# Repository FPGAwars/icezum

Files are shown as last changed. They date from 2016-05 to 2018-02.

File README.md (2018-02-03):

# Icezum Alhambra
Arduino/zum compatible **Open FPGA** electronic board.  Synthesize hardware easily, using **only open source tools**

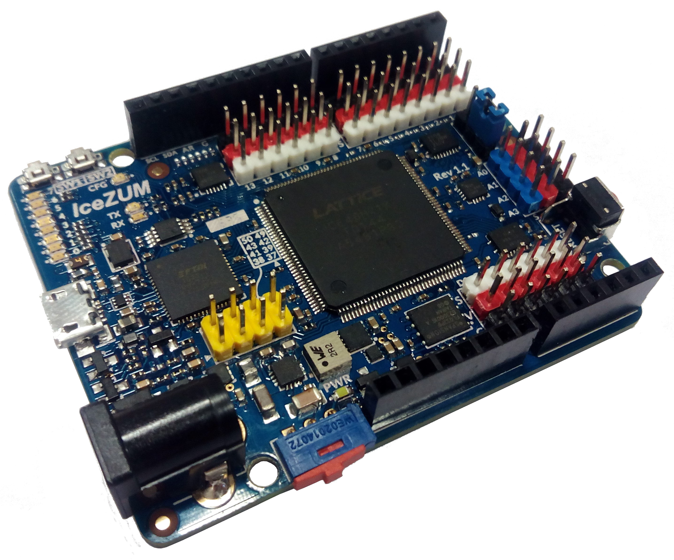
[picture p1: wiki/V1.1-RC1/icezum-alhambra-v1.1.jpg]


## Features

* FPGA development board ([iCE40HX1K-TQ144](https://github.com/Obijuan/open-fpga-verilog-tutorial/raw/master/tutorial/doc/iCE40LPHXFamilyDataSheet.pdf) from lattice)
* Open hardware
* Compatible with the [opensource icestorm toolchain](http://www.clifford.at/icestorm/)
* Arduino like board: similar pinout than Arduino one / [BQ zum](https://store.bq.com/es/placa-zum-core).
* You can Reuse most of available shields
* Control your robots / printbots from an FPGA
* 12 MHZ MEMS oscillator
* ON/OFF switch (turn off your mobile robot easily)
* Input power voltage: 6 - 17v
* Max input current: 3A (Perfect for powering your robots)
* 20 Input/output 5v pins
* 8 Input/Output 3.3V pins
* USB micro-B connector for programming the FPGA from the PC (same as zum board)
* [FTDI 2232H](www.ftdichip.com/Documents/DataSheets/ICs/DS_FT2232H.pdf) USB device allows FPGA programming and UART interface to a PC
* Reset pushbutton
* 8 general purpose leds (user leds)
* 2 general purpose pushbuttons
* 4 analogue inputs though I2C bus ([ADS7924](http://www.ti.com/lit/ds/symlink/ads7924.pdf) from TI)

## Documentation

[The project documentation is located in the wiki](https://github.com/FPGAwars/icezum/wiki)

## History

### Icezum Alhambra releases and EDA tools used over time

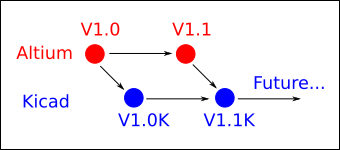
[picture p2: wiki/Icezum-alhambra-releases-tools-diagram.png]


### V1.0
* **2015-12-20**: The icezum board was conceived in the **BQlabs**, the robotics and innovation department at [BQ](https://www.bq.com/es/). The idea was to have a very easy to use FPGA board, fully openhardware, similar to Arduino/ZUM boards, so that anyone can connect sensors and create robots or small projects using an FPGA instead of a processor. We wanted to extend the educational approach of BQ to the digital circuits design. At that time, Juan Gonzalez (Obijuan) was the head of the department. Eladio Delgado, a very-skilled senior external engineer was assigned the task of designing the board. He was already involve in other projects with BQ

* **2016-02-18**: [The icezum board bqlabs repo](https://github.com/bqlabs/icezum) at github is created and all the V1.0 files released

*  **2016-02-29**: The board was renamed to **Icezum Alhambra** because Eladio lives in a small town in Granada. The name was suggested by **Sebastián Gallardo** in [this post in the FPGAwars community](https://groups.google.com/d/msg/fpga-wars-explorando-el-lado-libre/f1W0Vtt5NdE/LEDRSXudGwAJ) (In Spanish)

* **2016-03-05**: The first prototype is built and a bitstream is successfully upload into the board! [Images](https://github.com/FPGAwars/icezum/raw/master/doc/2016-03-04-Mounting-first-prototype/icezum-alhambra-mounting-15.jpg) 10 PCBs were manufactured in total. 5 Prototypes were mounted (by hand) by Eladio and his sister María. 5 more were mounted one mounth later

* **2016-04-14**: BQlabs was disolved and this proyect was stopped. Many thanks to BQ  for all its help during this period. Thanks for sponsoring the Icezum board

### V1.0K
* **2016-04-20**: The project is continued by the FPGAwars community, lead by Obijuan. The [FPGAwars github organization](https://github.com/FPGAwars)) is created and all the repositories related to openfpgas are moved there

* **2016-05-01**: A Small local crowdfunding is organized in the FPGAwars community ([Original message, in spanish](https://groups.google.com/d/msg/fpga-wars-explorando-el-lado-libre/oLFzYPqCOcQ/OsMxYKnuAQAJ)). Only 100 V1.1 boards will be manufactured if an amount of 6500€ is raised

* **2016/05/18**: After two weeks, we already have the commitment of the people for paying the money for building the boards ([Board funded!](https://groups.google.com/d/msg/fpga-wars-explorando-el-lado-libre/oLFzYPqCOcQ/luBcnXpBBwAJ))

* **2016/05/30**: The icezum Alhambra is being **migrated to Kicad** by Juan Gonzalez (Obijuan). Also the 3D models were designed with FreeCAD, so that the Icezum Alhambra is not only an openhardware board, but also a board **designed with opensource tools**. This way, anyone in the world can easily have access to all the designs, to study them, modify them and creating new boards from them. This version will be called V1.0K (K stands for kicad). It is not going to be manufactured, but rather a starting point for the future versions

* **2016/07/03**: All the money (6500€ in total) is received from the backers! Thanks a lot!!! ([Backers list](https://docs.google.com/spreadsheets/d/1yngU6kfMr5JWJYXrxBMJ7l1Cai2iuucMDoND4NpgU5Y))

* **2016/07/28**: V1.0K is released!

### V1.1

 * **2016/04/20**: In paralell with the V1.0K version, Eladio started to work on the V1.1, which is the one that will be manufactured for the backers. As there were still no Kicad version when Eladio started, It is being designed in Altium and will be migrated later to Kicad as the V1.1K version
 
 * **2016/09/22**: Three Icezum Alhambra V1.1-RC1 are hand mounted and tested. They work ok!. The PCBs were manufactured in pcbway. The design is validated

 * **2016/10/03**: [Icezum Alhambra v1.1-RC1 is released](https://github.com/FPGAwars/icezum/releases/tag/v1.1-RC1)
 
### V1.1K
 
 TODO

## Authors

* **V1.0**: [Eladio Delgado Mingorance](https://twitter.com/EladioDM). Sponsored by [BQ](https://www.bq.com/es/)
* **V1.0K**: Migrated to Kicad by Juan González (Obijuan). 3D models designed with FreeCAD. Everything is generated using only opensource tools (schematics, pcb, 3D models, pinout, BOM...). This version belongs to our T**echnological Heritage**
* **V1.1**: Eladio Delgado Mingorance, from Pinos del Valle, Granada, Spain

## Credits
* [BQ](https://www.bq.com/es/). Thanks for funding this project from 2015-12-20 to 2016-04-14. During this period, the icezum V1.0 was born and 10 prototypes were manufactured.
* María Delgado Mingorance, for helping in the manufacturing and design of the V1.0
* V1.0 was derived from the [Arduino Uno board](https://www.arduino.cc/en/Main/ArduinoBoardUno)
* V1.0 was derived from the [zum core board](https://github.com/bq/zum/tree/master/zum-core) by BQ
* V1.0 was derived from the [Icestick](http://www.latticesemi.com/icestick) by Lattice
* V1.0K was derived from Icezum Alhambra V1.0 by BQ
* V1.1 was derived from Icezum Alhambra V1.0 by BQ
* [Icestorm project](http://www.clifford.at/icestorm/), by Clifford Wolf and Mathias Lasser
* Icezum Pinout, by [Alberto Piganti](http://www.pighixxx.com/test/2016/05/icezum-pinout/)
* [Jairo Zerberos](https://github.com/zerberros). Migration of the FT2232H schematic symbol from altium to kicad. Thanks!
* [altium2kicad](https://github.com/thesourcerer8/altium2kicad]). Tool used for the migration from Altium to Kicad. Many thanks to the developers!
* [Kicadstepup](https://sourceforge.net/projects/kicadstepup/). Tool for exporting the board to FreeCAD
* [Alhambra festival picture](http://beentheredrawnthat.blogspot.com.es/2016/07/festivales-de-musica-y-danza-alhambra.html), by Cristina Urdiales. Thanks for this beautiful paiting!
* Juan González (Obijuan): V1.0 specifications. Migration to Kicad (V1.0K)

## Acknowledges
* Many thanks to [BQ](https://www.bq.com/es/), for funding the initial prototype V1.0, during the period 2015-12-20 to 2016-04-14. Thanks a lot for increasing our technological heritage by sponsoring openhardware boards.

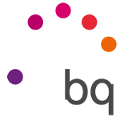
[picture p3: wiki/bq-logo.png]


## License

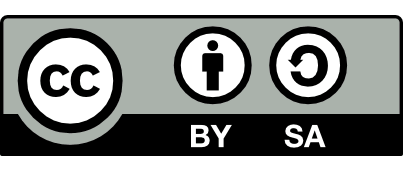
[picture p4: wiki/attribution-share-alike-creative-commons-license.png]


Licensed under [Creative Commons Attribution-ShareAlike 4.0 International License](http://creativecommons.org/licenses/by-sa/4.0/)

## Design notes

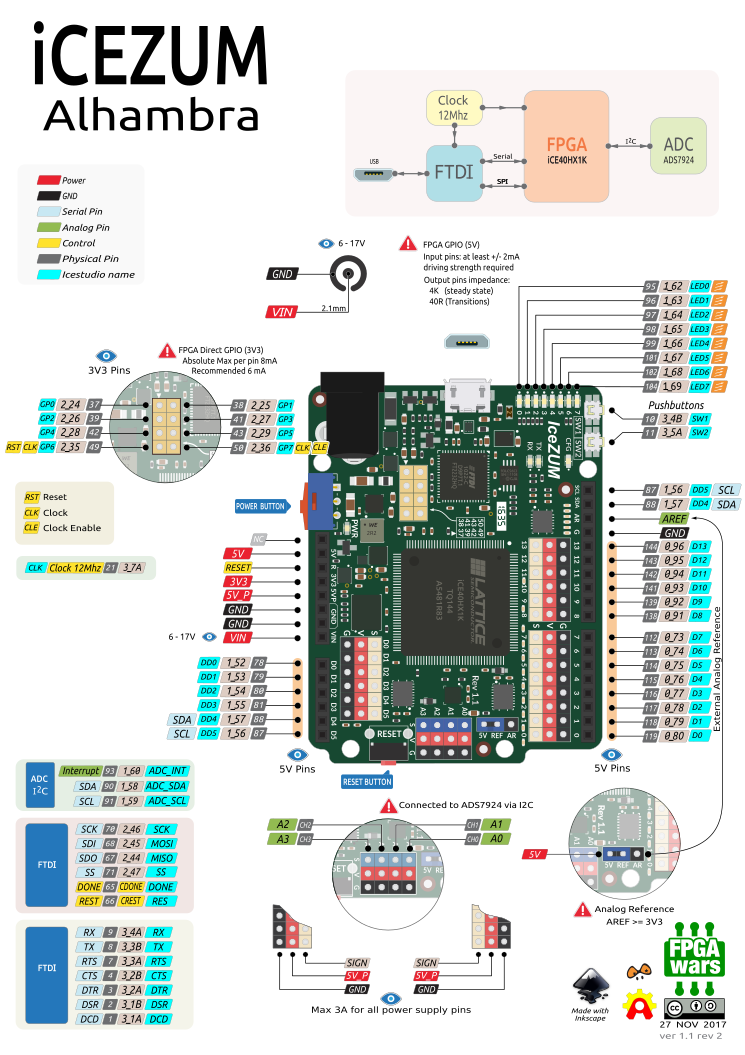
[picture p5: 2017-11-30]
doc/pinout/icezum-pinout.png

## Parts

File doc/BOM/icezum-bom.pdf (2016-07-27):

Icezum V1.0K BOM

ITEM | Reference | Description | Ordering Code | Manufacturer | Supplier | Footprint | Qty | OrderingCode 2 | Manufacturer 2 | Value
1 | C1,C2,C3,C4,C5,C6,C7,C8,C9,C10 C12,C13,C14,C15,C16,C18,C19 C20,C21,C23,C25,C26,C27,C28,C29 C30,C32,C33,C34,C35,C36,C37 C45,C46,C47,C48,C49,C50,C68 | SMD Capacitor | C0402C104K4RAC | Kemet | | C_0402 | 39 | | | 100nF ±10% 16V
2 | C11 | SMD Capacitor | EMK107BBJ106MA-T | Taiyo Yuden | | C_0603 | 1 | C1608X5R1C106M080AB | TDK | 10uF ±20% 16V
3 | C17,C24,C31,C41,C59,C64,C65 | SMD Capacitor | C1608X5R1C475K080AC | TDK | | C_0603 | 7 | | | 4.7uF ±10% 16V
4 | C22 | SMD Capacitor | C0603C103K3RAC | Kemet | | C_0603 | 1 | | | 10nF ±10% 25V
5 | C38,C39,C40,C42,C43,C44,C51, C52,C53,C54,C55,C56,C57,C58 | SMD Capacitor | C0402C101K4RAC | Kemet | | C_0402 | 14 | | | 100pF ±10% 16V
6 | C60,C62,C66,C70 | SMD Capacitor | C0603C104K3RAC | Kemet | | C_0603 | 4 | | | 100nF ±10% 25V
7 | C67 | SMD Capacitor | TMK316B7106KL-TD | kemet | | C_1206 | 1 | | | 10uF ±10% 25V
8 | C69 | SMD Capacitor | LMK316ABJ226ML-T | Taiyo Yuden | | C_1206 | 1 | | | 22uF ±20% 10V
9 | C71 | SMD Capacitor | GRM1885C1E621JA01D | Murata | | C_0603 | 1 | | | 620pF ±5% 25V
10 | D1 | Schottky Diode | MMDL101T1G | On Semiconductor | | SOD-323 | 1 | | | 100mA 7V
11 | D2,D3,D4,D5,D6,D7,D8,D9 | LED | LY Q971-H1L2-36 | OSRAM Opto | | LED_0603 | 8 | HSMY-C190 | Avago Technologies | Yellow
12 | D10 | Protection, Bidirectional Transient suppression Diode | SMAJ17CA | Bourns | | DO-214AC | 1 | SMAJ17CA | Littelfuse
13 | D11 | Dual Schottky Diode Common Cathode | BAT54C-G3-08 | Vishay | | SOT-23 | 1 | BAT54C | Fairchild | 200mA 30V
14 | D12 | LED | LW Q38G-Q2R2-3K5L-1 | OSRAM Opto | | LED_0603 | 1 | | | White
15 | D13 | Zener Diode | BZX384C5V1-E3 | Vishay | | SOD-323 | 1 | | | 5V1
16 | F1 | PTC Resettable Fuse | MF-MSMF050-2 | Bourns | Abacus | F_1812 | 1
17 | F2 | Protection, USB ESD | 82400152 | Würth | Würth | SOT-563 | 1 | CDSOT563-0502 | Bourns
18 | J1 | Connector, USB Micro B | 10118192-0001LF | FCI | Abacus | USB_Micro-B | 1 | ZX62-B-5PA-11 | Hirose Connector
19 | J2,J13 | 1x6 pin Header 2.54mm | TSW-106-07-T-S-RED | Samtec | Samtec | 1x6-pin-header-2.54mm | 2 | | | Red
20 | J3,J14 | 1x6 pin Header 2.54mm | TSW-106-07-T | Samtec | Samtec | 1x6-pin-header-2.54mm | 2 | 613 006 111 21 | Würth Elektronik | Black
21 | J6,J12 | 1x6 pin Header 2.54mm | TSW-106-07-T-NATURAL | Samtec | Samtec | 1x6-pin-header-2.54mm | 2 | | | white
22 | J4 | Connector, 10 pin Socket Header | SSW-110-01-T-S | Samtec | Samtec | 1x10_socket-header-2.54mm | 1 | 613 010 118 21 | Würth Elektronik
23 | J5,J10 | 8 pin Socket Header 2.54mm | SSW-108-01-T-S | Samtec | Samtec | 1x8_Socket_header_2.54mm | 2 | 613 008 118 21 | Würth Elektronik
24 | J7 | 1x8 pin Header 2.54mm | TSW-108-07-T-S-RED | Samtec | Samtec | 1x8_pin_header_2.54mm | 1 | | | Red
25 | J8 | 1x8 pin Header 2.54mm | TSW-108-07-T-S | Samtec | Samtec | 1x8_pin_header_2.54mm | 1 | 613 008 111 21 | Würth Elektronik | Black
26 | J9 | 1x8 pin Header 2.54mm | TSW-108-07-T-S-NATURAL | Samtec | Samtec | 1x8_pin_header_2.54mm | 1 | | | White
27 | J11 | 6 pin Socket Header 2.54mm | SSW-106-01-T-S | Samtec | Samtec | 1x6-Socket-header-2.54mm | 1 | 613 006 118 21 | Würth Elektronik
28 | J15 | Connector, 1x4 pin Header 2.54mm | TSW-104-07-T-S-RED | Samtec | Samtec | 1x04-pin-header-2.54mm | 1 | | | Red
29 | J16 | Connector, 1x4 pin Header 2.54mm | TSW-104-07-T-S | Samtec | Samtec | 1x04-pin-header-2.54mm | 1 | 613 004 111 21 | Würth Elektronik | Black
30 | J17 | Connector, 1x4 pin Header 2.54mm | TSW-104-07-T-S-BLUE | Samtec | Samtec | 1x04-pin-header-2.54mm | 1 | 613 004 111 21 | Würth Elektronik | Cyan
31 | J18 | Connector, Power, DC Power Jack | KLDHCX0202A | Kycon | Avnet | JACK_2.1 | 1 | RAPC722X | Switchcraft
32 | J19 | Connector, 8 pin Dual Header 2.54mm | TSW-104-07-T-D | Samtec | Samtec | 2x04-pin-header-2.54mm | 1 | 613 008 211 21 | Würth Elektronik
33 | JP1 | Connector, Jumper, 3 pin Male Header 2.54mm | 613 003 111 21 | Würth | Würth | 1x03-pin-header-2.54mm | 1
34 | JPM1 | 1x2 Jumper 2.54mm | 609 002 136 21 | Würth | Würth | | 1
35 | L1 | Inductor SMD | LQM21FN100M70L | Murata | | L_0805 | 1 | | | 10uH 0,1A
36 | L2,L4 | Ferrite Bead | BLM18SG121TN1D | Murata | | L_0603 | 2 | | | 120R 0,025R 3000mA
37 | L3 | Ferrite Bead | MPZ1608S221A | TDK | | L_0603 | 1 | | | 220R 0,05R 2200mA
38 | L5 | Inductor SMD | 74438356022 | Würth | Würth | L_4040 | 1 | XAL4020-222MEB | Coilcraft | 2,2uH 4,7A
39 | Q1,Q2,Q4 | P-Channel MOSFET, 6 pin | DMP3017SFK-7 | Diodes Inc. | Silica | DFN-2523-6 | 3
40 | Q3 | PFET | DMP2035U-7 | Diodes Inc. | Silica | SOT-23 | 1
41 | Q5 | PNP | PMBT3906,215 | NXP | | SOT-23 | 1
42 | R1,R3,R4,R5,R6,R7,R8, R12,R13,R14 R20,R21,R28,R37,R38 | Resistor, SMD | CRCW040210K0JN | Vishay | | R_0402 | 15 | | | 10k±5% 0.063w
43 | R2 | Resistor, SMD | CRCW0402470RJN | Vishay | | R_0402 | 1 | | | 470R ±5% 0.063W
44 | R9 | Resistor, SMD | CRCW0402100RJN | Vishay | | R_0402 | 1 | | | 100R ±5% 0.063W
45 | R10,R25,R39 | Resistor, SMD | CRCW04021K00JN | Vishay | | R_0402 | 3 | | | 1k ±5% 0.063W
46 | R11 | Resistor, SMD | CRCW040212K0FK | Vishay | | R_0402 | 1 | | | 12k ±1% 0.063W
47 | R15 | Resistor, SMD | CRCW04022K20JN | Vishay | | R_0402 | 1 | | | 2k2 ±5% 0.063W
48 | R16,R32,R33,R35 | Resistor, SMD | ERJ-2GE0R00X | Panasonic | | R_0402 | 4 | CRCW04020000Z0 | Vishay | 0R ±5% 0.063W
49 | R17,R18 | Array of 4xResistors, SMD | CAY16-271J4LF | Bourns | | R_Array_Convex_4x0603 | 2 | | | 270R ±0,5% 0,0625W
50 | R19 | Resistor, SMD | CRCW040210R0JN | Vishay | | R_0402 | 1 | | | 10R ±5% 0.063W
51 | R22,R23 | Resistor, SMD | CRCW04024K70JN | Vishay | | R_0402 | 2 | | | 4k7 ±5% 0.063W
52 | R24,R27 | Resistor, SMD | CRCW040247K0JN | Vishay | | R_0402 | 2 | | | 47k ±5% 0.063W
53 | R26,R29,R30,R31 | Resistor, SMD | CRCW0402100KJN | Vishay | | R_0402 | 4 | | | 100k ±5% 0.063W
54 | R34 | Resistor, SMD | CRCW04025K60JN | Vishay | | R_0402 | 1 | | | 5k6 ±5% 0.063W
55 | R36 | Resistor, SMD | CRCW0402220KJN | Vishay | | R_0402 | 1 | | | 220k ±5% 0.063W
56 | SW1,SW2 | Micro miniature pushbutton Surface Switch | 434 121 025 816 | Würth | Würth | SW_SMD_60X3.8 | 2 | KSR231GLFS | Cannon, ITT ind.
57 | SW3 | SPDT Switch, Right Angle | 450 302 014 072 | Würth | Würth | slide-sw-spdt-right-angle | 1 | MMP1010D-RA | Knitter-Switch
58 | SW4 | Micro miniature pushbutton Surface Switch | PTS645VL39-2 LFS | C&K Components | Abacus | SW_vert_tht_7.5x6x6.5 | 1
59 | U1 | iCE40 HX1K Series FPGA Family, 1280 Logic Cells, 1.2 V Core, 64 K Embedded RAM Bits, 144-pin TQFP, Pb-Free, Tray | iCE40HX1K-TQ144 | Lattice | | TQFP-144_IPC-MD | 1
60 | U2 | NOR Flash Memory, serial | N25Q032A13EF640E | Micron | Silica | DFN-8-6x5mm | 1 | S25FL032P0XNFI011 | Spansion | 32Mb
61 | U3 | Dual High Speed USB to Multipurpose UART/FIFO IC | FT2232HQ-REEL | FTDI | Silica | FTDI-QFN-64 | 1
62 | U4 | Oscillator, Low-Power CMOS, 4 pin, 1.8-3.3V | DSC1001CL2-012.0000 | Microchip | | Xtal-3_2x2_5 | 1 | | | 12MHz
63 | U5 | EEPROM, 2K Microwire Compatible Serial, 8 or 16 bit word size, 2.5-5.5 Vcc range | 93LC56CT-I/MS | Microchip | Silica | MSOP-8_3x3mm_Pitch0.65mm | 1 | | | 2Kb
64 | U6 | Voltage Translator, Hex | TXB0106RGYR | Texas Instruments | Silica | VQFN16 | 1
56 | U7 | ADC Converter, 12-Bit, 4-Ch, I2C | ADS7924IRTER | Texas Instruments | Silica | QFN16 | 1
66 | U8 | Voltage Level Translator, 8-Bit Bidir., TP | TXS0108ERGYR | Texas Instruments | Silica | VQFN20 | 1
67 | U9 | Voltage Level Translator, 8-Bit Bidir., TP | TXB0108RGYR | Texas Instruments | Silica | VQFN20 | 1
68 | U10 | LDO Regulator, 8 pin, adjustable And fixed mode with enable | AP7361-33FGE-7 | Diodes Inc. | Silica | DFN-3030-8 | 1
69 | U11 | LDO Regulator, Dual, 6 pin | TLV7111233DSER | Texas Instruments | Silica | WSON-6 | 1
70 | U12 | 3A High Efficient Synchronous Step Down Converter with DCS™ Control | TPS62133RGTR | Texas Instruments | Silica | QFN16 | 1

Made with LibreOffice

Icezum Alhambra V1.0K (Kicad-edition) BILL OF MATERIALS

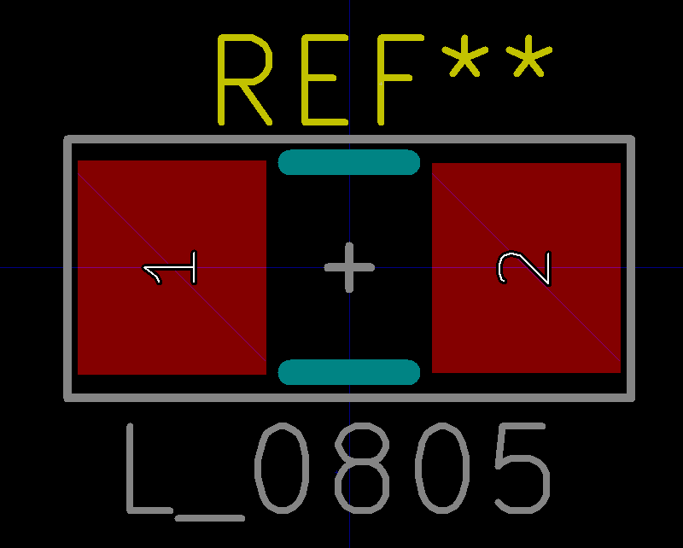
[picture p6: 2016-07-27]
wiki/V1.0K/3D-components/L_0805-footprint.png

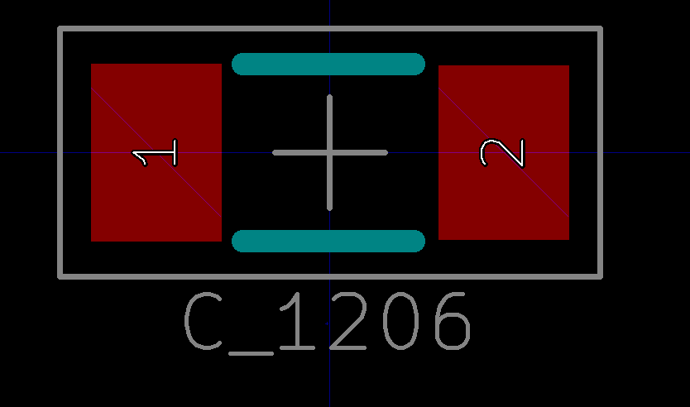
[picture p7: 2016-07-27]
wiki/V1.0K/3D-components/C_1206-footprint.png

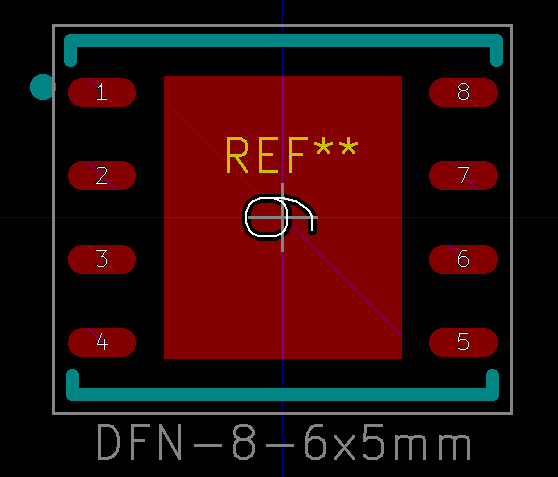
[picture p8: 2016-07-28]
wiki/V1.0K/3D-components/DFN-8-6X5mm-footprint.png

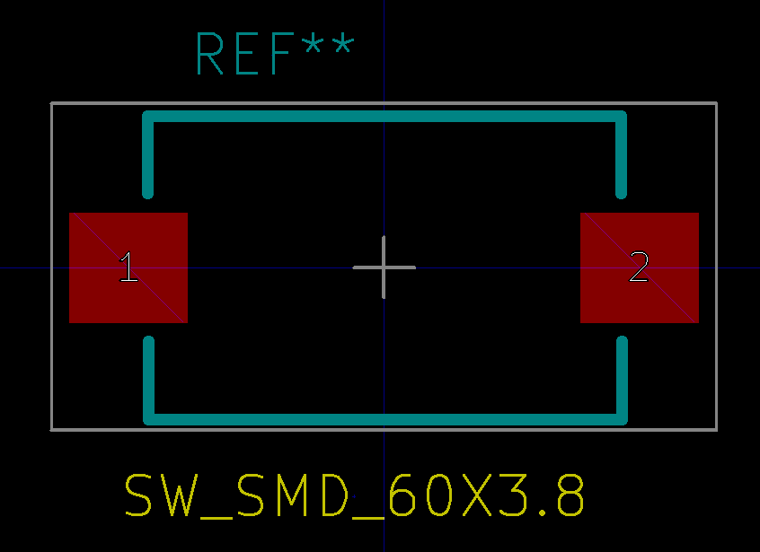
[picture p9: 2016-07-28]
wiki/V1.0K/3D-components/SW_smd_60x3.8-footprint.png

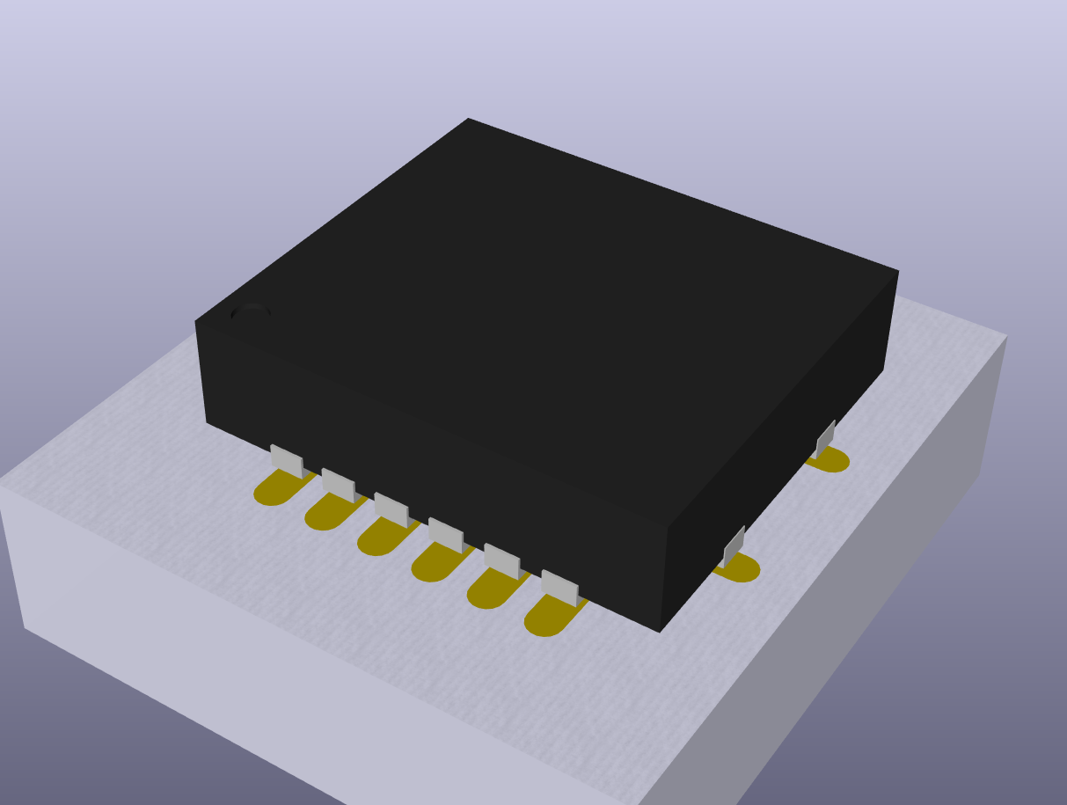
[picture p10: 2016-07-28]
wiki/V1.0K/3D-components/VQFN16-3D.png

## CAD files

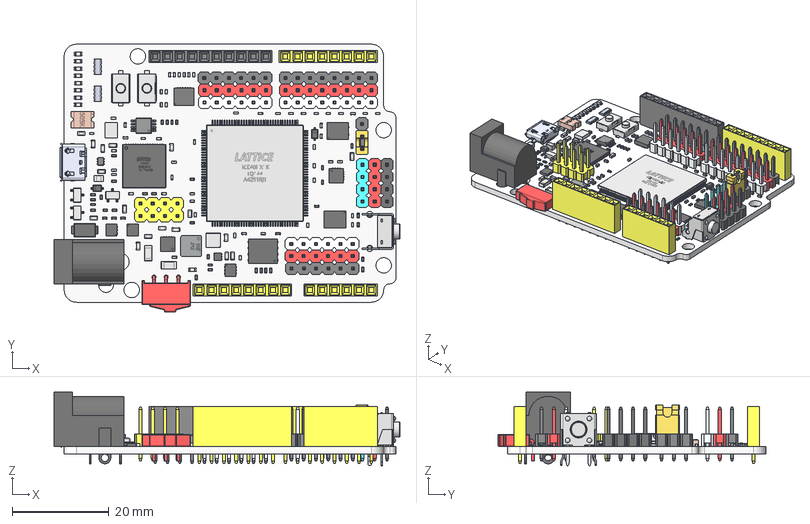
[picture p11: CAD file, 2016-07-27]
3D/icezum.FCStd
71.5 x 55.3 x 15.2 mm
Pcb
LED_0603_
LED_0603_001
LED_0603_002
LED_0603_003
LED_0603_004
LED_0603_005
LED_0603_006
LED_0603_007
sw_smd_6.0x3.8_
sw_smd_6.0x3.8_001
LED_0603_008
R_Array_4x0603_
R_Array_4x0603_001
PVQFN20_
PVQFN20_001
1x10-socket-header_
1x6-pin-header_
1x6-pin-header_001
1x6-male-pin-header-gray_
1x6-male-pin-header-gray_001
1x6-male-pin-header-red_
1x6-male-pin-header-red_001
1x8-socket-header_
1x8-male-pin-header_
1x8-male-pin-header-red_
1x8-male-pin-header-gray_
1x8-socket-header_001
1x6-socket-header_
1x4-male-pin-header_
1x4-male-pin-header-red004_
1x4-male-pin-header-cyan_
2x4-pin-header-yello_
USB-micro-B_
jack_DC_2.1mm_PCB_
slide-sw-right-angle_
F1812-505k_
xtal-3_2x2_5_
MSOP-8_
SOT-563_
SOT23-3_
SOT23-3_001
SOT23-3_002
SOD-323_
DO-214AC_
DFN-2523-6_
DFN-2523-6_001
FTDI-QFN-64_
QFN16_
QFN16_001
L_4040_
PVQFN16_
DFN-2523-6_002
TQFP-144_
DFN-3030-8_
WSON-6_
SOD-323_001
DFN-8-6x5mm_
pushbutton-right-angle_
L_0603_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

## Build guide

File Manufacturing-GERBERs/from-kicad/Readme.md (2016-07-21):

* **icezum-Edge.cuts.gbr**: Mechanical layer 1 (*icezum-GM1*)
* **icezum-F.Cu.gbr**: Copper Top layer (*icezum-GTL*)
* **icezum-B.Cu.gbr**: Copper Bottom layer (*icezum-GBL*)
* **icezum-In1.Cu.gbr**: Copper Inner layer 1 (*icezum-G1*)
* **icezum-In2.Cu.gbr**: Copper Inner layer 2 (*icezum-G2*)
* **icezum-F.SilkS.gbr**: Top SilkScreen Layer (*icezum-GTO*)
* **icezum-B.SilkS.gbr**: Bottom SilkScreen Layer (*icezum-GBO*)
* **icezum-F.Mask.gbr**: Top Solder Mask Layer (*icezum-GTS*)
* **icezum-B.Mask.gbr**: Bottom Solder Mask Layer (*icezum-GBS*)
* **icezum-F.Paste.gbr**: Top Paste layer (*icezum-GTP*)
* **icezum.drl**: Drills

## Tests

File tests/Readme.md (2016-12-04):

# Tests for the Icezum Alhambra v1.1  

Tools:  Apio 0.1.6.2  / Icestudio 0.2.1

* **Test 01**: Turning all leds on
* **Test 02**: Testing the pushbuttons. SW1 and SW2 are connected to led0 and led1 respectively
* **Test 03**: Testing the RTS and DTR signals coming from the PC. They are shown in the leds led0 and led7 respectively
* **Test 04**: Testing the serial communication at 115200 bauds. All the received characters are echoed back to the PC, and shown in the leds
* **Test 05**: Testing the external IR sensors on D13 and D12 inputs
* **Test 06**: Testing a servo connected to D13. The position is changed when the SW1 button is pressed

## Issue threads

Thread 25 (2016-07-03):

KiCad example loading

gh-jmg, 2016-07-03:
Hi,
Nice project. Checking the nice KiCad ported files you have I see some small issues

a) SCH files open, but minus some symbols.
    I need to go Preferences.Component Libraries, and add your local library to the list.
   Then, all symbols render OK

b) icezum.KiCad_pcb seems load parts and outline correctly, but looks to be 100% unrouted ? (no traces?)
Or, is it intentional this is unrouted ?

Obijuan, 2016-07-03:
Hi!

Thanks for you feedback

a) Checkout the develop branch and test it again: https://github.com/FPGAwars/icezum/tree/develop

The library should be automatically loaded. If not, please, tell me in this issue

b) The board is currently being routed in the develop branch. All the placement is finished, all the 3D component have modeled (in freecad) and the routing is 20% (only the first layer). I hope that the migration to kicad will be finished in around two weeks

Any feedback is welcome :-)

gh-jmg, 2016-07-03:
Hi Juan,

a) Checkout the develop branch and test it again:
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
I'll check this tomorrow.

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
ok, I was not sure if that unrouted was accidental.Look forward to seeing
the finished design.
If you do this in Altium, you could consider release of both P-CAD and
KiCad formats, as the kiCad PCAD importer is being improved all the time.
That also allows Eagle users to import the design too.

Did you consider doing anything with the Lattice 48 pin QFN iCE5x series ?
They still lack an eval board for those....

Obijuan, 2016-07-03:
> If you do this in Altium, you could consider release of both P-CAD and KiCad formats, as the kiCad PCAD importer is being improved all the time. That also allows Eagle users to import the design too.

Thanks for the tip!

> Did you consider doing anything with the Lattice 48 pin QFN iCE5x series ? They still lack an eval board for those....

I am not sure if that series are supported by the opensource icestorm toolschain. If not, they will be in the future, I am sure

gh-jmg, 2016-07-05:
Hi Juan,

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
I'm curious, if you have this routed in Altium, why do you need to re-route
it in KiCad ?
Did the porting/translation pathways have some issues ?

-jg

Obijuan, 2016-07-05:
I am just routing it myself for learning Kicad. Also for learning all the icezum details. The board was routed by Eladio, a college of mine, in Altium. I want to re-do it again in Kicad, for having in mind all the details.

gh-jmg, 2016-07-05:
HI Juan,

I am just routing it myself for learning Kicad.
>
Ah, that makes sense.

> Also for learning all the icezum details.
>
The board was routed by Eladio, a college of mine, in Altium.
>
I want to re-do it again in Kicad, for having in mind all the details.
>
You should be able to import from Altium, but I guess it depends on how
many changes are also merged in.
I've found KiCad seems to tolerate small end alignment deviations, (ie
slightly off exact pad centre)

I'm also new to KiCad, but it is growing on me,
The Shove router is very nice, and has better cleaning algorithms than
Mentors.
The mouse wheel navigation with rate-based zoom is also novel, and the more
I use that, the more adept I get and the more I like it. One hand for
navigate and one hand for commands, is nice.

gh-jmg, 2016-07-22:
Hi Juan,

I see a finished? design recently posted - looks nice :)

Some comments/observations

C31 is labeled 4.7nF, but maybe meant 4.7uF ?

When I use MicroUSB, I choose ones with through-holes (eg 4x)  on the outer
framework.
Usually those are short, (< 1.6mm), but give both location and more
strength and less likely to 'rip-off' from accidents.

regards
Jim G.

Obijuan, 2016-07-24:
>  see a finished? design recently posted - looks nice :)

Thanks! It is almost finished

> Some comments/observations C31 is labeled 4.7nF, but maybe meant 4.7uF ?

Yeah! It is a bug. I've already fix it in [this commit](https://github.com/FPGAwars/icezum/commit/6cd7838ead1d836aee266f3c594ddf4b5326ba79).  Thanks a lot for reporting:-)

> When I use MicroUSB, I choose ones with through-holes (eg 4x) on the outer framework. Usually those are short, (< 1.6mm), but give both location and more strength and less likely to 'rip-off' from accidents

Thanks for the advice. It makes more sense to use your MicroUSB.  We will use them in future versions

I will close this issue. If you have further comments or bugs, please do not hesitate on filling a issue

Thanks for you help  ;-)

gh-jmg, 2016-08-16:
Hi Juan,

Using this design as a nice test for kiCad scripts, I notice a couple of
things :

a) There are a few thermal vias, that have imported as parts from Altium

This gives a skew to the BOM and netlist
BOM has ~ 26 extra parts like this...
VIA**   pad-via
VIA**   pad-via
Netlist has 26 extra nodes
VIA**.~

BOM and Netlist will be cleaner, & need less manual cleanup, if those
Thermal Vias can be swallowed into the footprints ?

b) Some entities are modules with zero pads, so I added a test to skip
these.
(These can also confuse the BOM )
These may be just dummy place keepers ?

*REMARK* Skipped doc1 (has 0 Pads)
*REMARK* Skipped DOC1 (has 0 Pads)
*REMARK* Skipped doc7 (has 0 Pads)
*REMARK* Skipped doc2 (has 0 Pads)
*REMARK* Skipped doc3 (has 0 Pads)
*REMARK* Skipped doc10 (has 0 Pads)
*REMARK* Skipped DOC3 (has 0 Pads)
*REMARK* Skipped doc4 (has 0 Pads)
*REMARK* Skipped doc5 (has 0 Pads)
*REMARK* Skipped doc6 (has 0 Pads)
*REMARK* Skipped doc8 (has 0 Pads)
*REMARK* Skipped doc9 (has 0 Pads)
*REMARK* Skipped JPM1 (has 0 Pads)
*REMARK* Skipped DOC4 (has 0 Pads)
*REMARK* Skipped DOC5 (has 0 Pads)
*REMARK* Skipped G*** (has 0 Pads)
*REMARK* Skipped REF*** (has 0 Pads)
*REMARK* Skipped DRILL2 (has 0 Pads)
*REMARK* Skipped DRILL4 (has 0 Pads)
*REMARK* Skipped DRILL3 (has 0 Pads)
*REMARK* Skipped DRILL1 (has 0 Pads)

regards
Jim G

Obijuan, 2016-08-16:
Hi @gh-jmg !

I've created two new issues to discuss there: #28 and #29

Thanks a lot!

gh-jmg, 2016-08-18:
Hi Juan,

FYI, I just came across this
http://www.zofzpcb.com/

A 3D Gerber viewer, quite impressive.
I plotted using Altium GBR names, which it seems to better sense of, & I
drop a .D356 file into the GBR directory.

It can also load IPC356, and check a design.

So,  I feed latest Icezum into this.... just to see what happens...

See attached image - it has mostly inferred correct 3D info :)

The Via** parts have confused it a little, as it thinks they are all *one*
part, so it makes a  single, large rectangle covering all Via**, and it
also thinks they are pins, so renders as that, with 'bonus spines'.

Moving those thermal vias into footprints, (or even just as manual Vias) as
suggested before, should clean that up.

It renders non-trace holes differently from trace-holes for some strange
reason, I think a ZofzPCB bug ?

It renders U6 with a strange angle spin, not sure why ?

Hmm, looking closely, U6 is unusual, and it has guessed a ~SO16N (almost,
pin pitch is *not* same on each side ?), and maybe the pin-centroid is
skewed (tho centroid seems square to me ?)
That may be a ZofzPCB quirk, but is is doing a quite good job of inferring
3D onto the Gerber + IPC info

Attached is the Screen grab, and the IPC error report.

 I see some Gerbers from your github have teardrops - were those Kicad
plotted ?

There is this
https://forum.kicad.info/t/yet-another-python-teardrop-script-adds-and-deletes-teardrops-to-a-pcb-v0-3-0/3388
I suggested he add Curved Teardrops, and they are now in :) - I've not
tested this yet.

ICP356 Netlis v.s. PCB copper test
965 total testpoints processed

27 of No-copper testpoint errors
No copper for Testpoint +5V_P layer both at (41.7,  43.8)mm
No copper for Testpoint +5V_P layer both at (39.1,  43.8)mm
No copper for Testpoint +5V_P layer both at (36.6,  43.8)mm
No copper for Testpoint +5V_P layer both at (34.0,  43.8)mm
No copper for Testpoint +5V_P layer both at (31.5,  43.8)mm
No copper for Testpoint +5V_P layer both at (29.0,  43.8)mm
No copper for Testpoint +5V_P layer both at (47.0,  9.5)mm
No copper for Testpoint +5V_P layer both at (49.5,  9.5)mm
No copper for Testpoint +5V_P layer both at (52.1,  9.5)mm
No copper for Testpoint +5V_P layer both at (54.6,  9.5)mm
No copper for Testpoint +5V_P layer both at (57.2,  9.5)mm
No copper for Testpoint +5V_P layer both at (59.7,  9.5)mm
No copper for Testpoint +5V_P layer both at (63.5,  43.8)mm
No copper for Testpoint +5V_P layer both at (61.0,  43.8)mm
No copper for Testpoint +5V_P layer both at (58.4,  43.8)mm
No copper for Testpoint +5V_P layer both at (55.9,  43.8)mm
No copper for Testpoint +5V_P layer both at (53.3,  43.8)mm
No copper for Testpoint +5V_P layer both at (50.8,  43.8)mm
No copper for Testpoint +5V_P layer both at (48.3,  43.8)mm
No copper for Testpoint +5V_P layer both at (45.7,  43.8)mm
No copper for Testpoint NET-(J5-PAD1) layer both at (27.9,  2.5)mm
No copper for Testpoint +5V_P layer both at (64.2,  28.4)mm
No copper for Testpoint +5V_P layer both at (64.2,  25.9)mm
No copper for Testpoint +5V_P layer both at (64.2,  23.3)mm
No copper for Testpoint +5V_P layer both at (64.2,  20.8)mm
No copper for Testpoint NET-(J18-PAD2) layer both at (8.7,  3.6)mm
No copper for Testpoint NET-(SW3-PAD1) layer both at (18.6,  5.2)mm

0 of Short-Circuit errors
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

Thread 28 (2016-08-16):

Include the thermal vias in the footprints

Obijuan, 2016-08-16:
Reported by @gh-jmg:

Hi Juan, Using this design as a nice test for kiCad scripts, I notice a couple of things :

a) There are a few thermal vias, that have imported as parts from Altium
This gives a skew to the BOM and netlist
 BOM has ~ 26 extra parts like this...
VIA** pad-via
 VIA** pad-via
 Netlist has 26 extra nodes
 VIA**.~

BOM and Netlist will be cleaner, & need less manual cleanup, if those Thermal Vias can be swallowed into the footprints ?

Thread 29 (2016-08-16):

Modules with 0 pads confuse BOM

Obijuan, 2016-08-16:
Reported by @gh-jmg

Hi Juan,

Using this design as a nice test for kiCad scripts, I notice a couple of things :

b) Some entities are modules with zero pads, so I added a test to skip these. (These can also confuse the BOM ) These may be just dummy place keepers ?

 *REMARK* Skipped doc1 (has 0 Pads)
 *REMARK* Skipped DOC1 (has 0 Pads)
*REMARK* Skipped doc7 (has 0 Pads)
*REMARK* Skipped doc2 (has 0 Pads)
*REMARK* Skipped doc3 (has 0 Pads)
*REMARK* Skipped doc10 (has 0 Pads)
*REMARK* Skipped DOC3 (has 0 Pads)
*REMARK* Skipped doc4 (has 0 Pads)
*REMARK* Skipped doc5 (has 0 Pads)
*REMARK* Skipped doc6 (has 0 Pads)
*REMARK* Skipped doc8 (has 0 Pads)
*REMARK* Skipped doc9 (has 0 Pads)
*REMARK* Skipped JPM1 (has 0 Pads)
*REMARK* Skipped DOC4 (has 0 Pads)
*REMARK* Skipped DOC5 (has 0 Pads)
*REMARK* Skipped G*** (has 0 Pads)
*REMARK* Skipped REF*** (has 0 Pads)
*REMARK* Skipped DRILL2 (has 0 Pads)
*REMARK* Skipped DRILL4 (has 0 Pads)
*REMARK* Skipped DRILL3 (has 0 Pads)
*REMARK* Skipped DRILL1 (has 0 Pads)

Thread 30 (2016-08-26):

Error in the 3D PVQFN20 package

Obijuan, 2016-08-26:
Reported by **Eladio Delgado** (through personal email). The PVQFN20 pins where not correctly aligned with the footprint

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

Obijuan, 2016-08-26:
Fixed! Eladio Delgado sent me the fixed Freecad file. Thanks!

Closed 2016-08-26.

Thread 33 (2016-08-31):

Migrate the v1.1 schematic to kicad

Obijuan, 2016-08-31:

AntonioMR, 2017-10-25:
Hello
I have almost finished migrating the schema from version 1.1 to kicad.
I am working on my local branch v1.1kicad not merged with local master.
is it okay if I send pull-requests on this branch, to merge with remote/master only when complet the migration? any other suggestions?

Obijuan, 2017-10-26:
Great! Yes! That is perfect! :-)  go ahead!!

AntonioMR, 2017-10-26:
Hello again,
It's seems I'm not able to send a Pull Request over a branch that it's not previously created, or I don't know how to do it. A possible workaround is:
- You create in your repository a local branch v1.1-kicad and push it to the icezum repository, so I will be able to send a PR to that branch.
- I push my local branch to an v1.1-kicad branch on my icezum repository fork. You fetch this branch on an local branch in your repository and then you push it to the icezum repository in github.
Do you know any other solution? Please let me know.

Obijuan, 2017-10-26:
I've already created the v1.1-kicad branch from master. Try to commit there

AntonioMR, 2017-10-26:
Thanks,
Done!

Obijuan, 2017-10-27:
I think this issue is fixed and can be closed.  Thanks a lot for your contribution! :-)

Closed 2017-10-27.

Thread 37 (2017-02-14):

order?

phil123456, 2017-02-14:
hi ,

I cant find any web site to order these....

Obijuan, 2017-02-14:
Hi,

Currently is not on sale. We are organizing small local crowdfundings for funding the batches. Batch 1 was finished (110 units). Now we are manufacturing the Batch 2 (250 units). The backers are helping us on the FPGAwars list (but i is only in spanish).

Is it possible that for the following batches we launch a more global crowdfunding compain

moebiussurfing, 2017-03-23:
Hola buenas, me gustaría participar en el crowfounding y adquirir alguna unidad, es posible? gracias

1138-4EB, 2017-03-24:
> Hola buenas, me gustaría participar en el crowfunding y adquirir alguna unidad, es posible? gracias

https://groups.google.com/forum/#!topic/fpga-wars-explorando-el-lado-libre/a5mmxIj4IcM
https://groups.google.com/forum/#!topic/fpga-wars-explorando-el-lado-libre/wOaLSpkVSII

Closed 2017-03-27.

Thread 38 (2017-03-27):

KiCad project grid mismatch

rogerdahl, 2017-03-27:
Apologies if this is not related to icezum. I'm using the icezum KiCad project to experiment with KiCad. When I open `icezum.kicad_pcb` in KiCad, the grid settings in KiCad do not update to match those used in the icezum project, so when I modify the design or add tracks, the modifications do not line up with the original design. I don't see why the grid spacing and origin wouldn't be included in the project, so I'm wondering if this is an issue with the icezum project? If there is no way to set them from the project, could you let me know what they are, so that I can set them manually?

Obijuan, 2017-03-27:
The size is not stored in the project properties because is something that you change very often when designing the PCB.  I am showing to you some values you can use

* For the schematics:

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

* For the PCB:

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

Closed 2017-03-27.

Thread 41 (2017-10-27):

Review the V1.1K schematics

Obijuan, 2017-10-27:
The schematics for the Icezum Board V1.1K has been migrated from Altium to Kicad by @AntonioMR
This issue will closed when Eladio Delgado review the new schematics

Thanks a lot Antonio!

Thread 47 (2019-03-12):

Issues with Icestudio in Mac OS

lozano9698, 2019-03-12:
I am having problems by charging programs on de Icezum Alhambra. It seems like something is not correct with the drivers because every time I try to charge a code apears: "Icezum Alhambra not conected". Using Mac OS Mojave.

Best regards

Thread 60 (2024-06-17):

Bottom pad of the FT2232HQ should be grounded.

zapta, 2024-06-17:
This is an FYI, in case somebody will respin this design.  According to the FT2232HQ datasheet, the bottom large pad of the QFN64 package should be grounded. Currently it's left floated.

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

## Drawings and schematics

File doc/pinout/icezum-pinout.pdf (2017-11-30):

# iCEZUM

# Alhambra USB

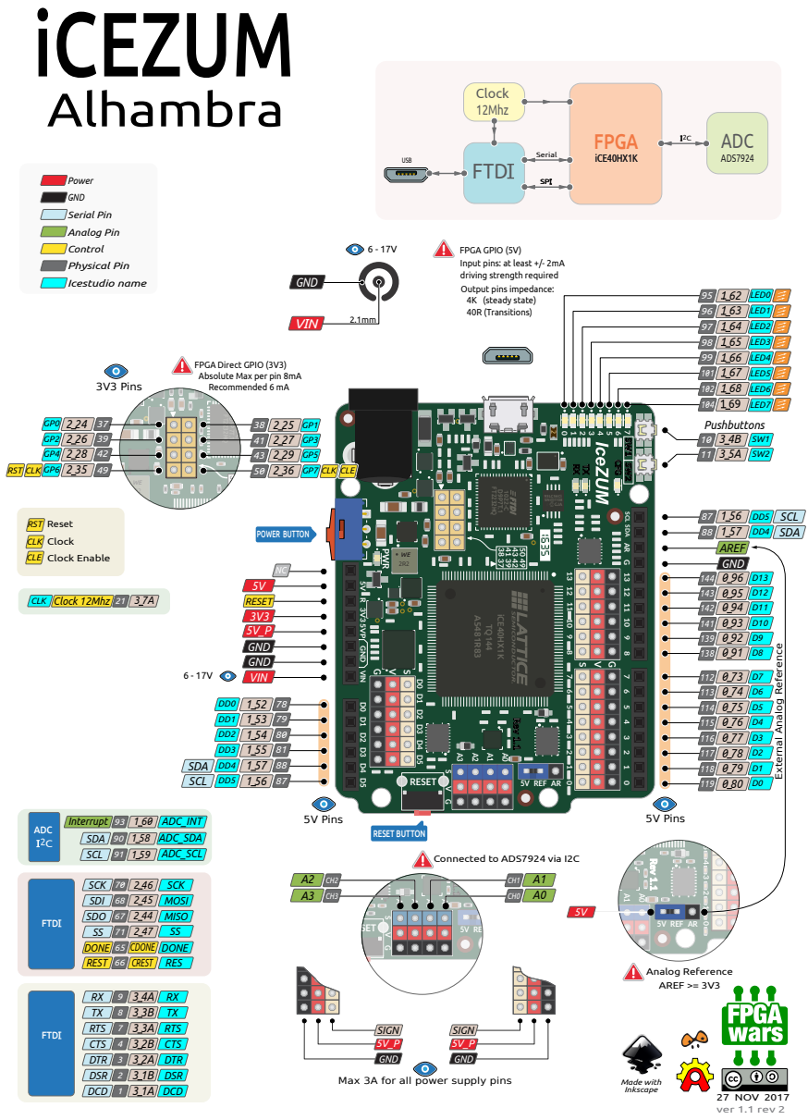
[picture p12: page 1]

FPGA GPIO (5V)
Input pins: at least +/- 2mA
driving strength required
Output pins impedance:
4K (steady state)
40R (Transitions)

FPGA Direct GPIO (3V3) D9P7T.1 1022-C FT2232HQ
Absolute Max per pin 8mA
Recommended 6 mA

Max 3A for all power supply pins

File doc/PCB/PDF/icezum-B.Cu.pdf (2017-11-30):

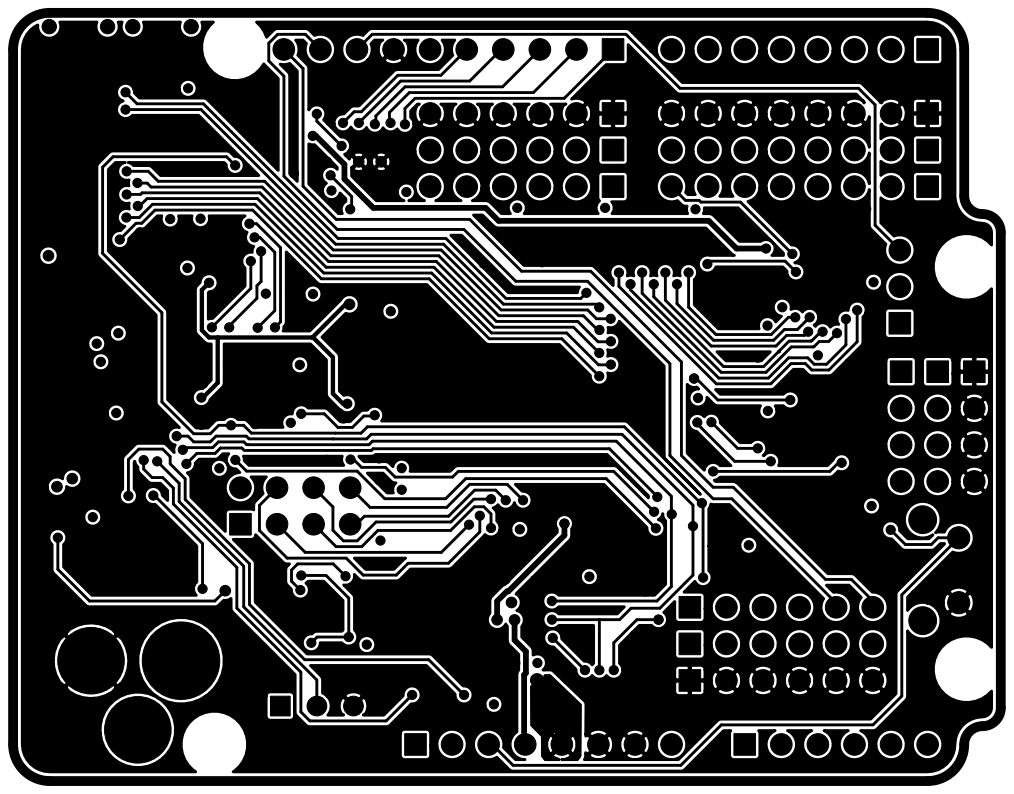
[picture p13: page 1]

License: Creative commons Attribution ShareAlike
Author: Eladio Delagado Mingorance
Migration to kicad: Juan Gonzalez (Obijuan)
File: icezum.kicad_pcb Sheet: FPGAwars Derived from BQ Icezum V1.0

Id: 1/1 Title: IceZUM Alhambra FPGA board (PCB)

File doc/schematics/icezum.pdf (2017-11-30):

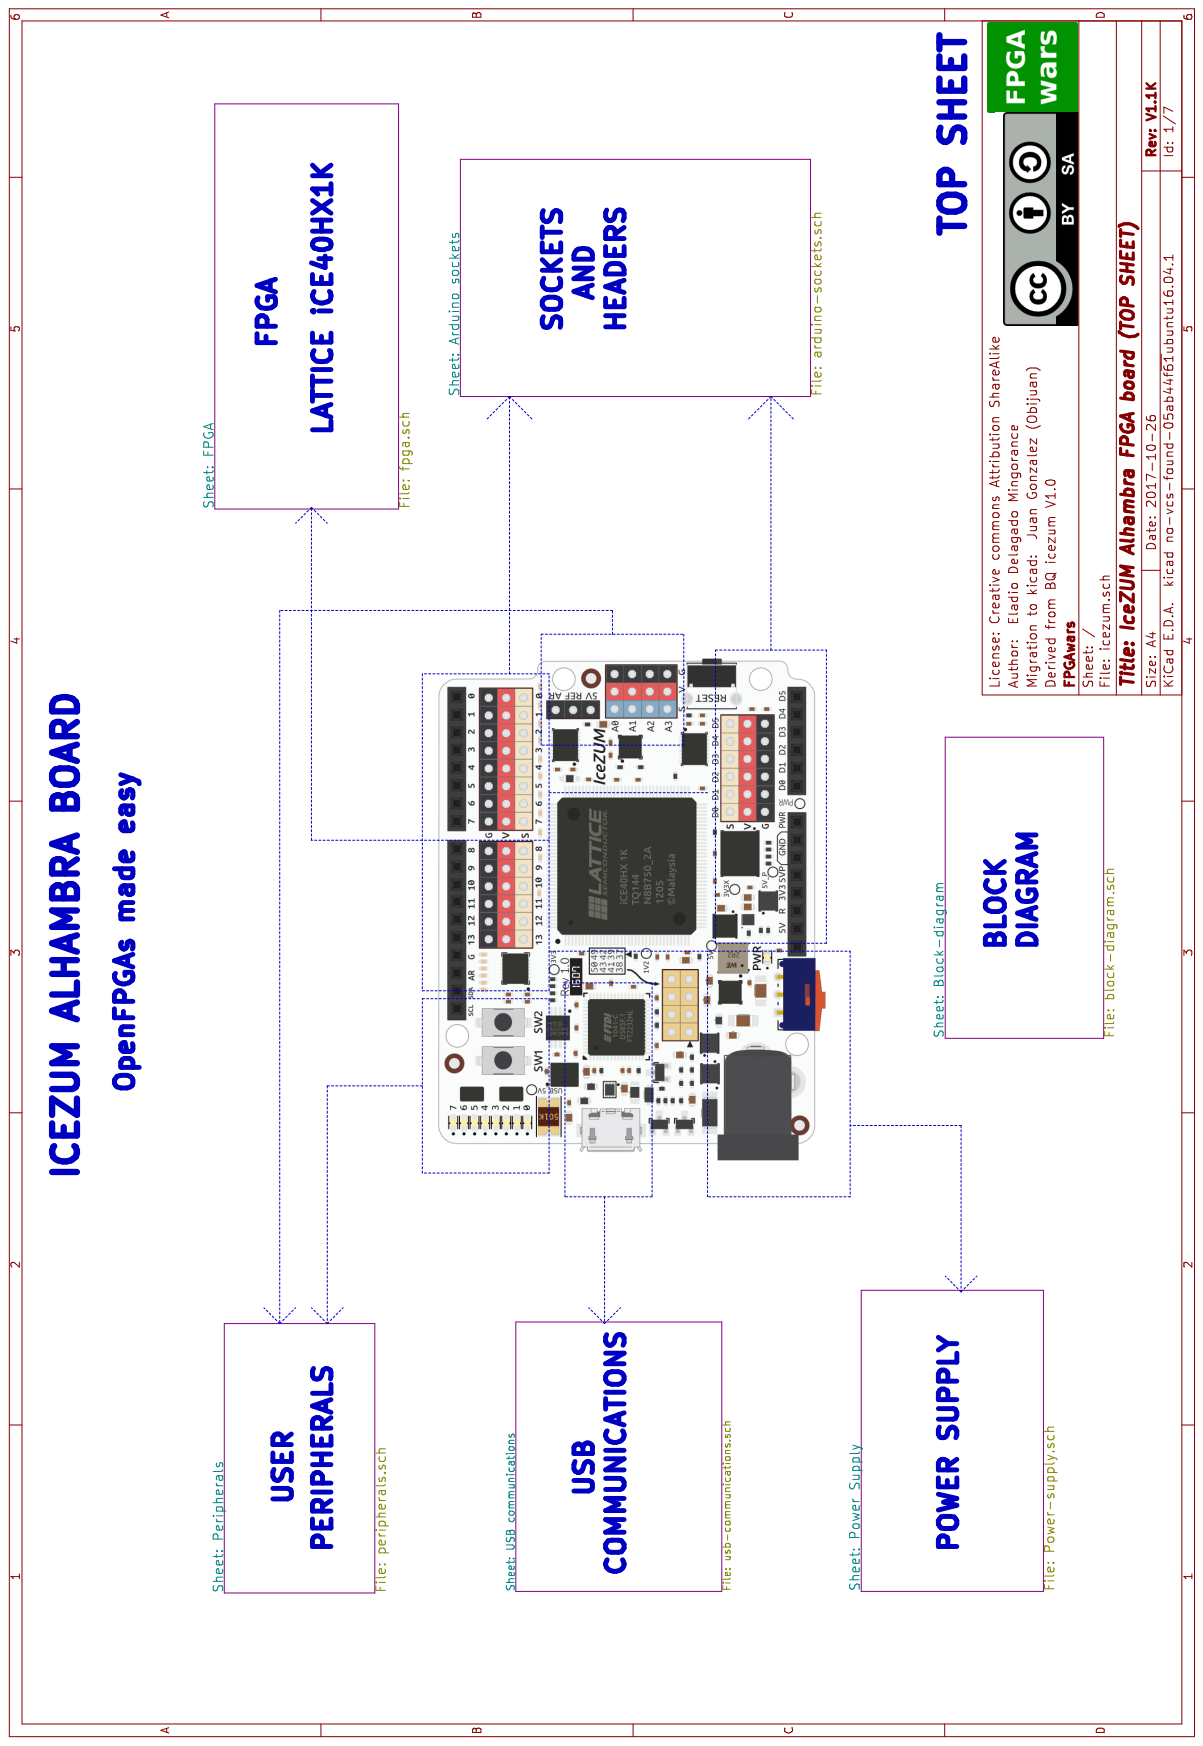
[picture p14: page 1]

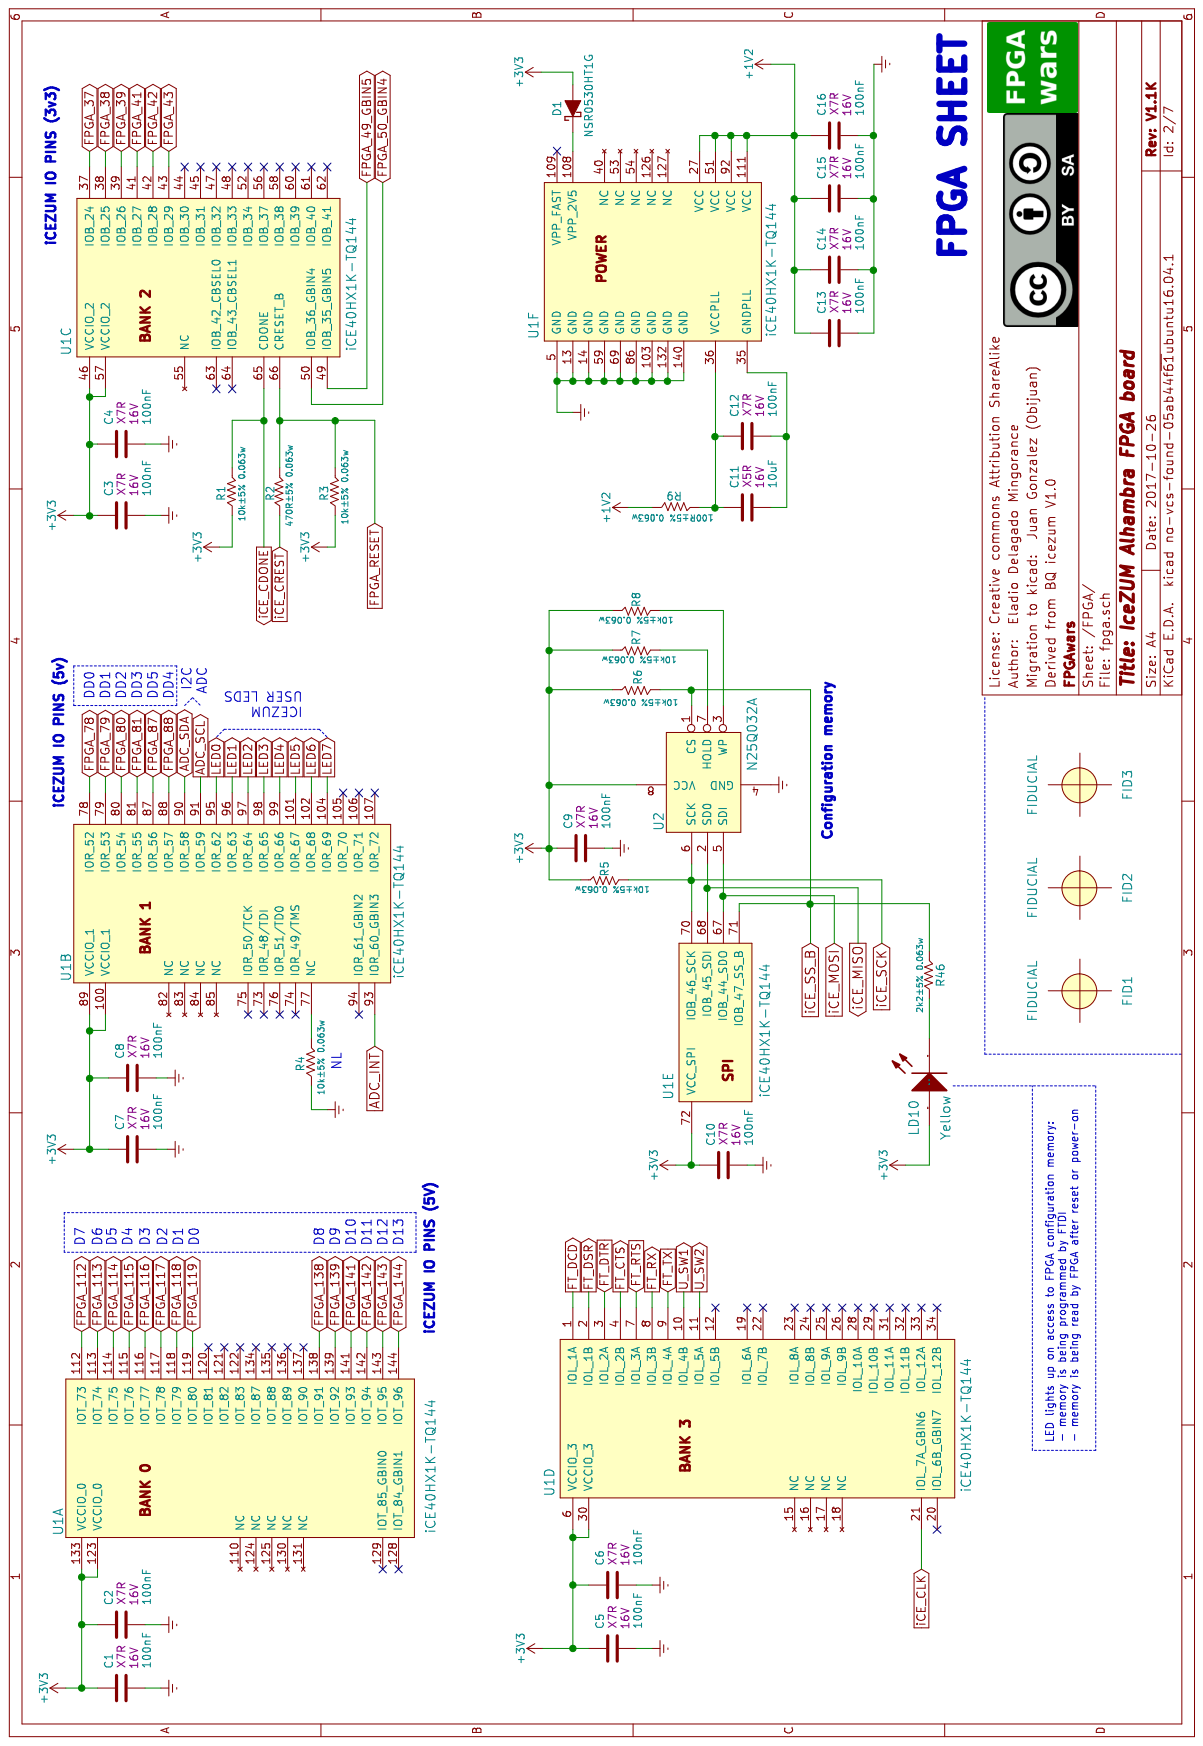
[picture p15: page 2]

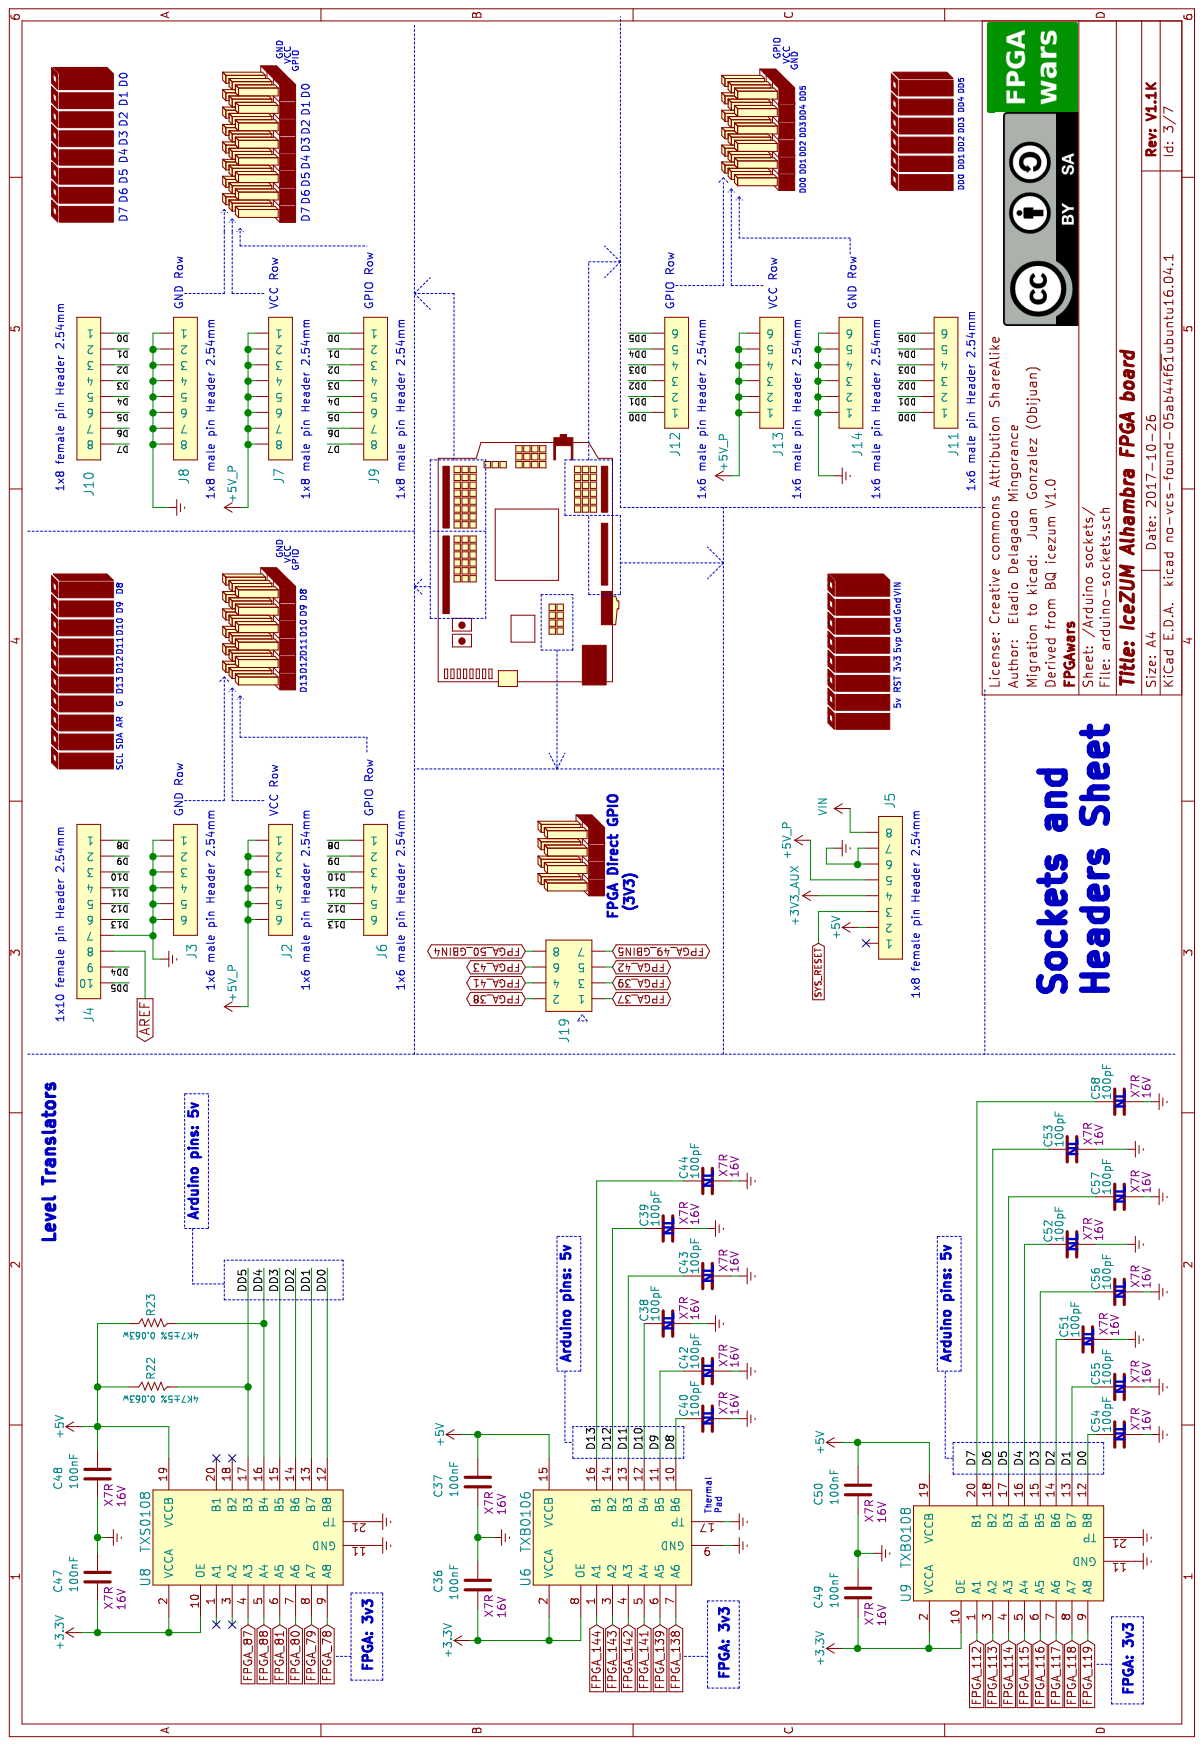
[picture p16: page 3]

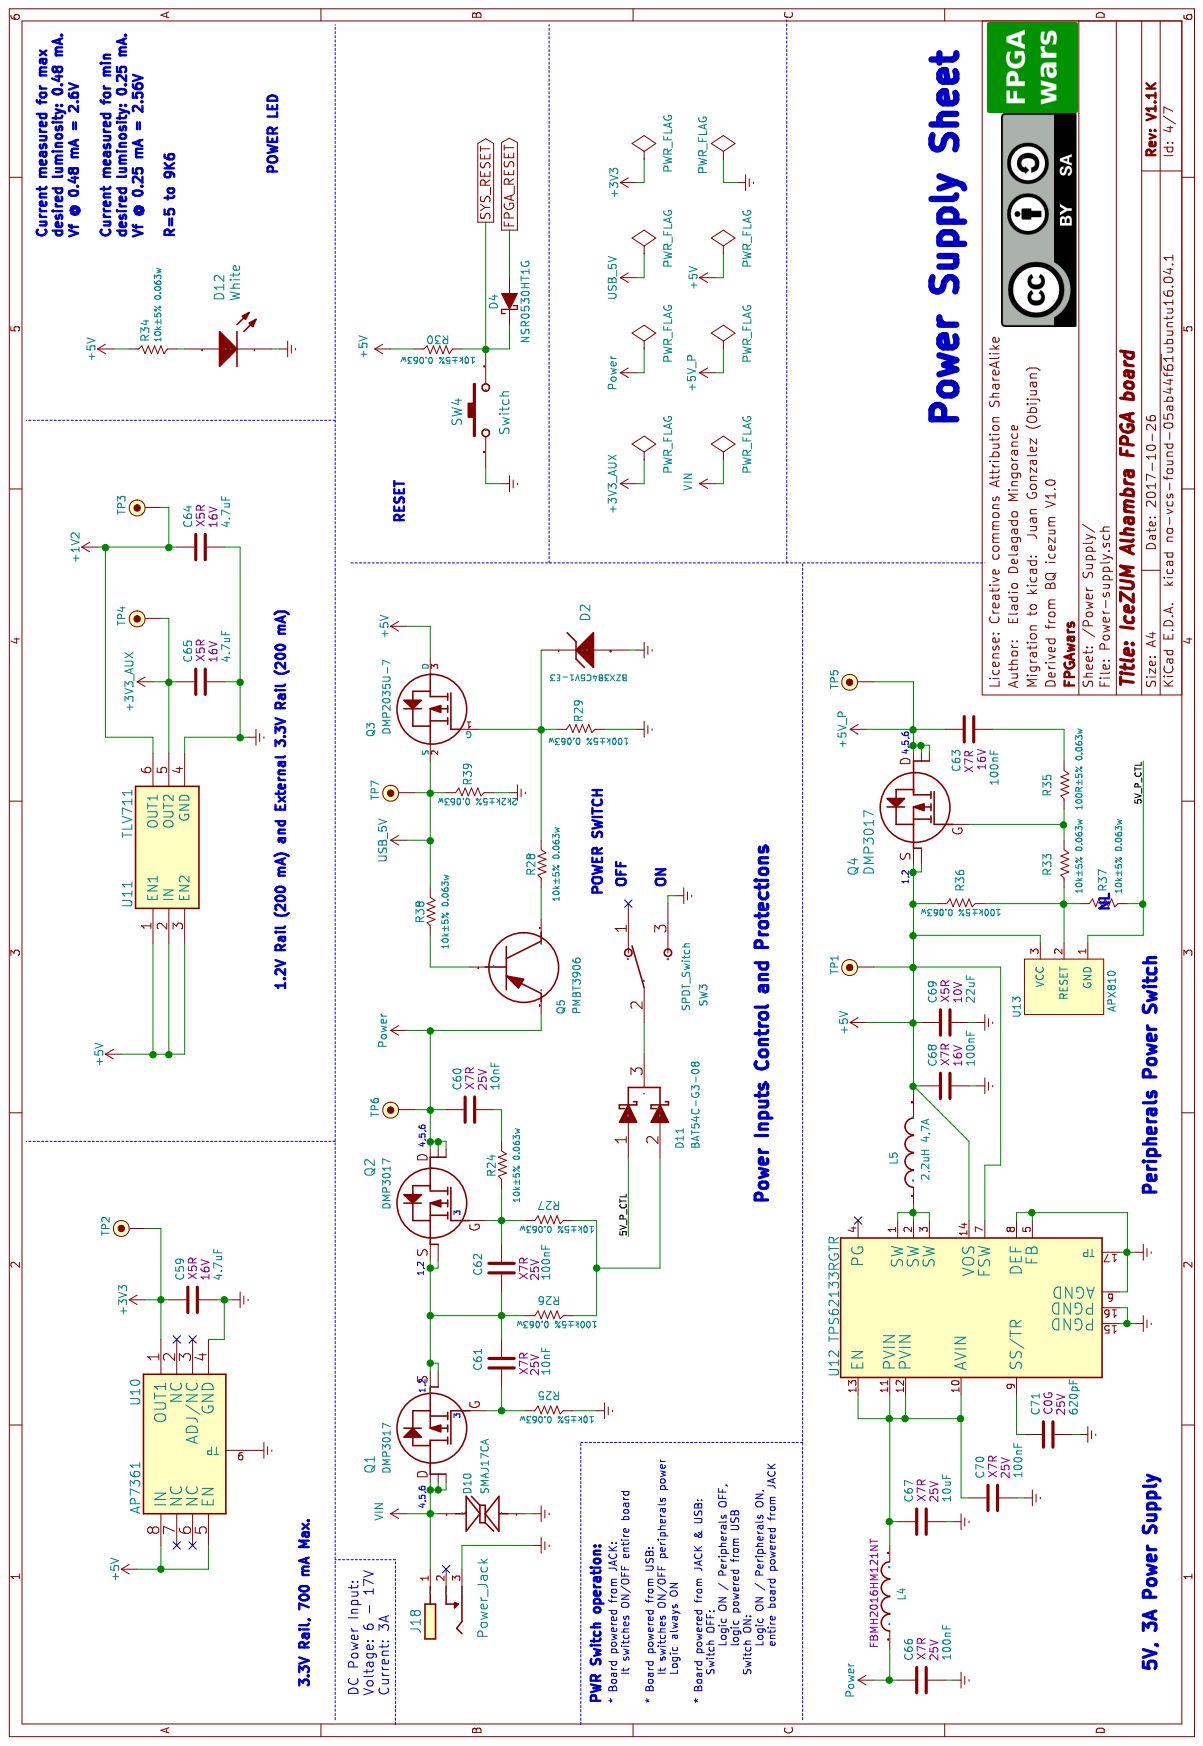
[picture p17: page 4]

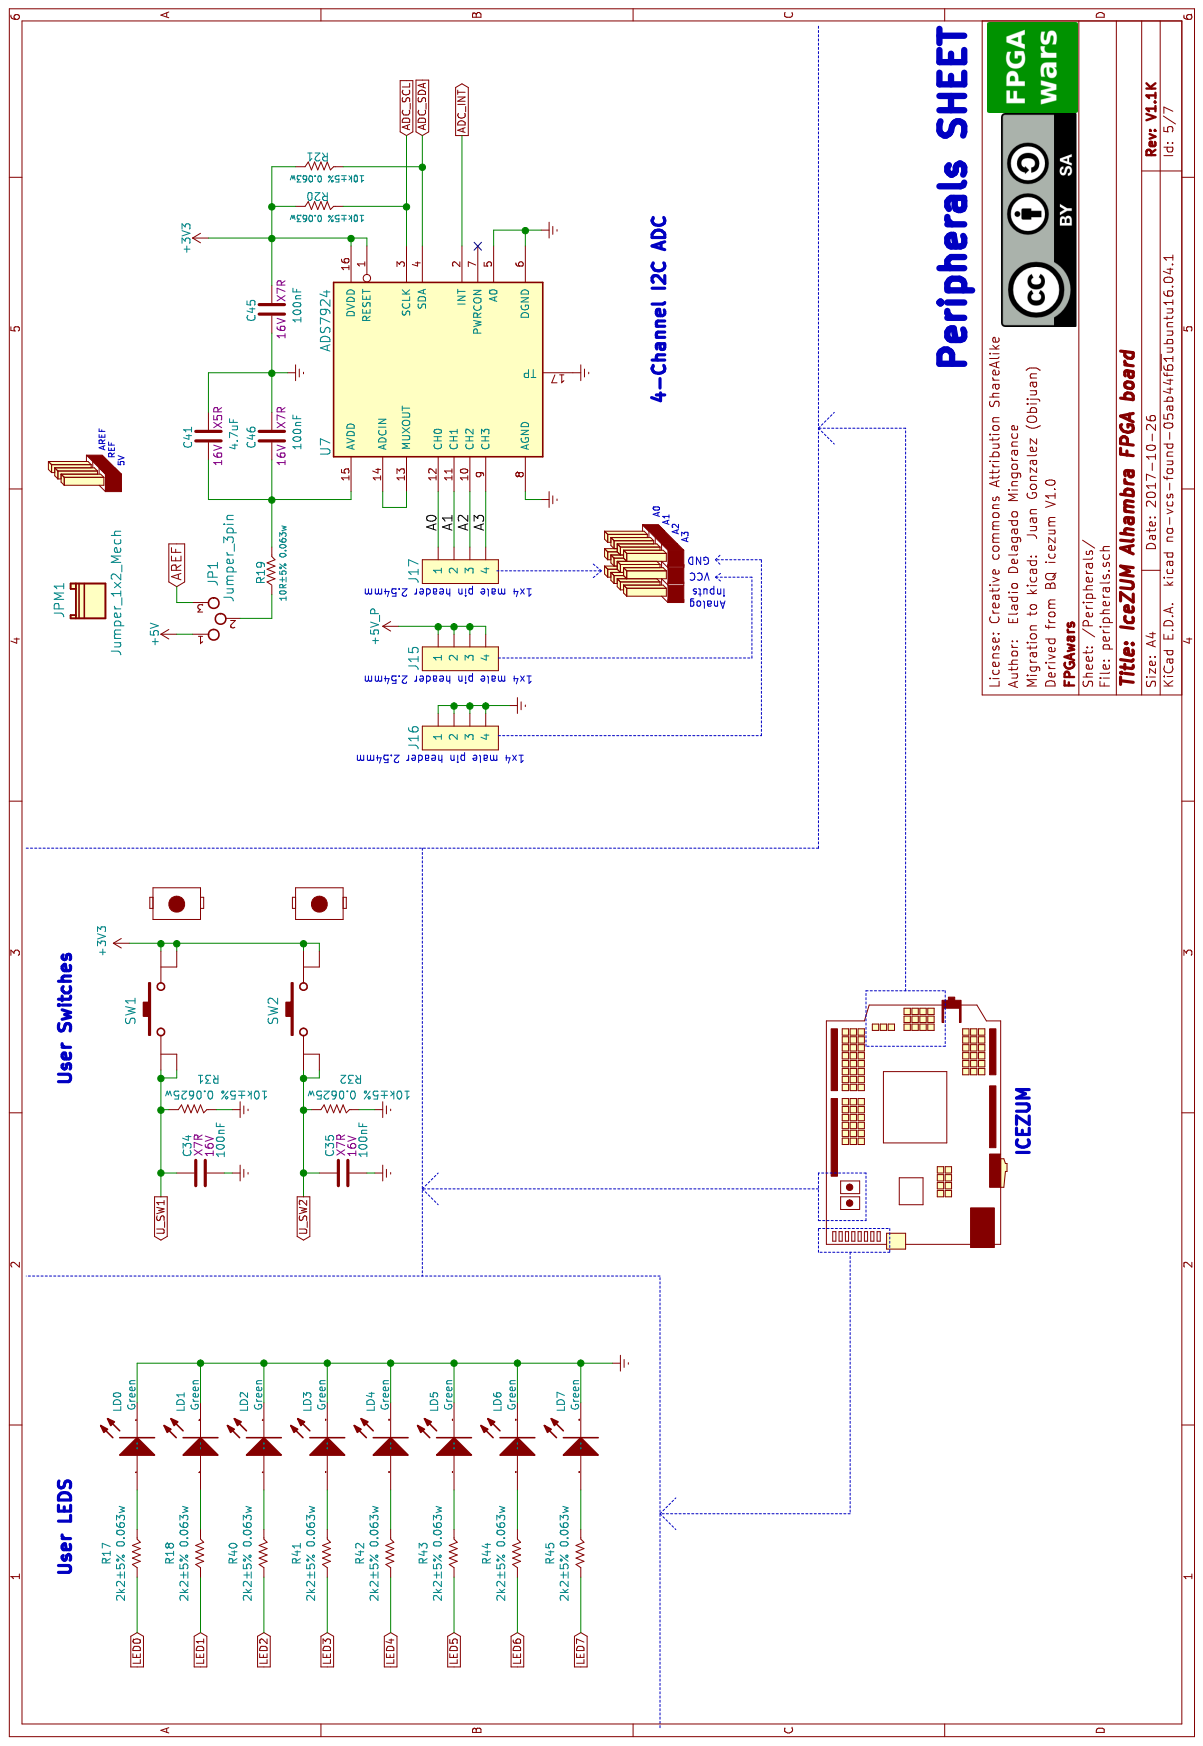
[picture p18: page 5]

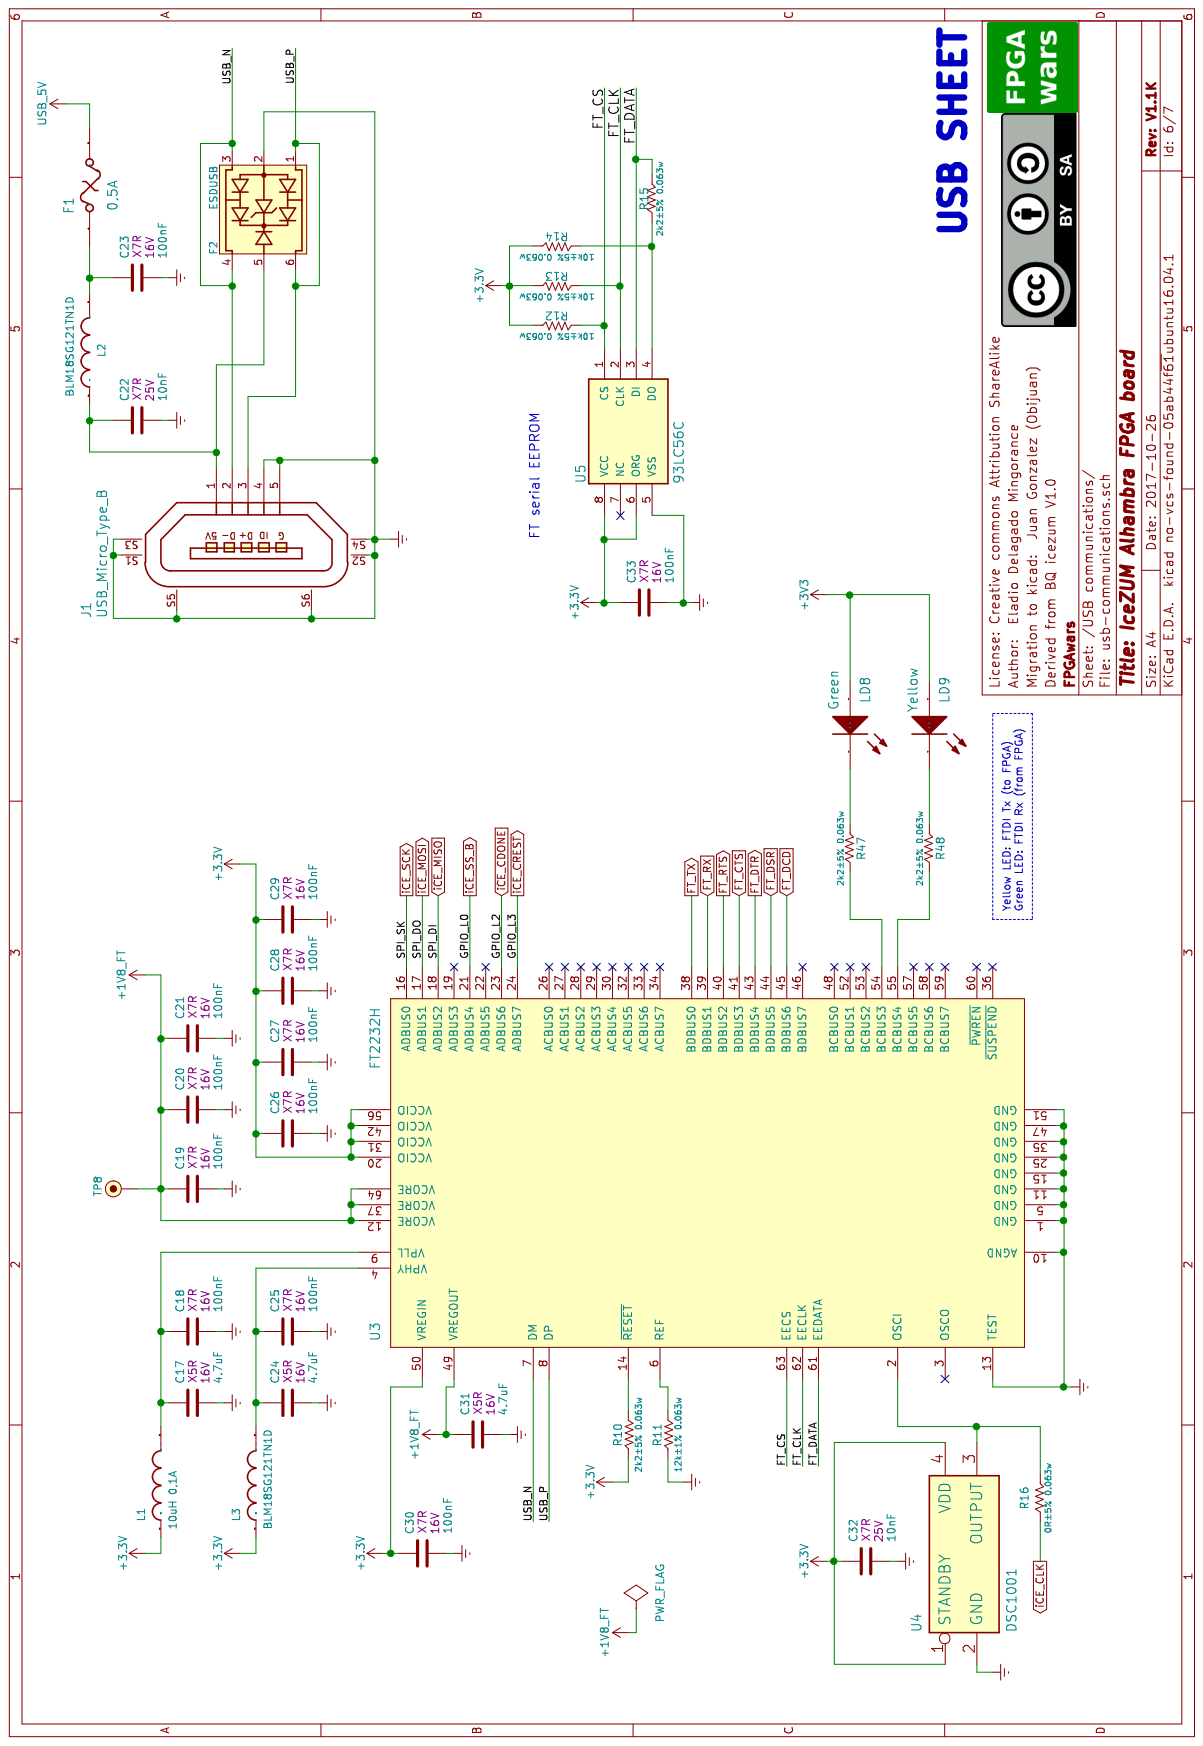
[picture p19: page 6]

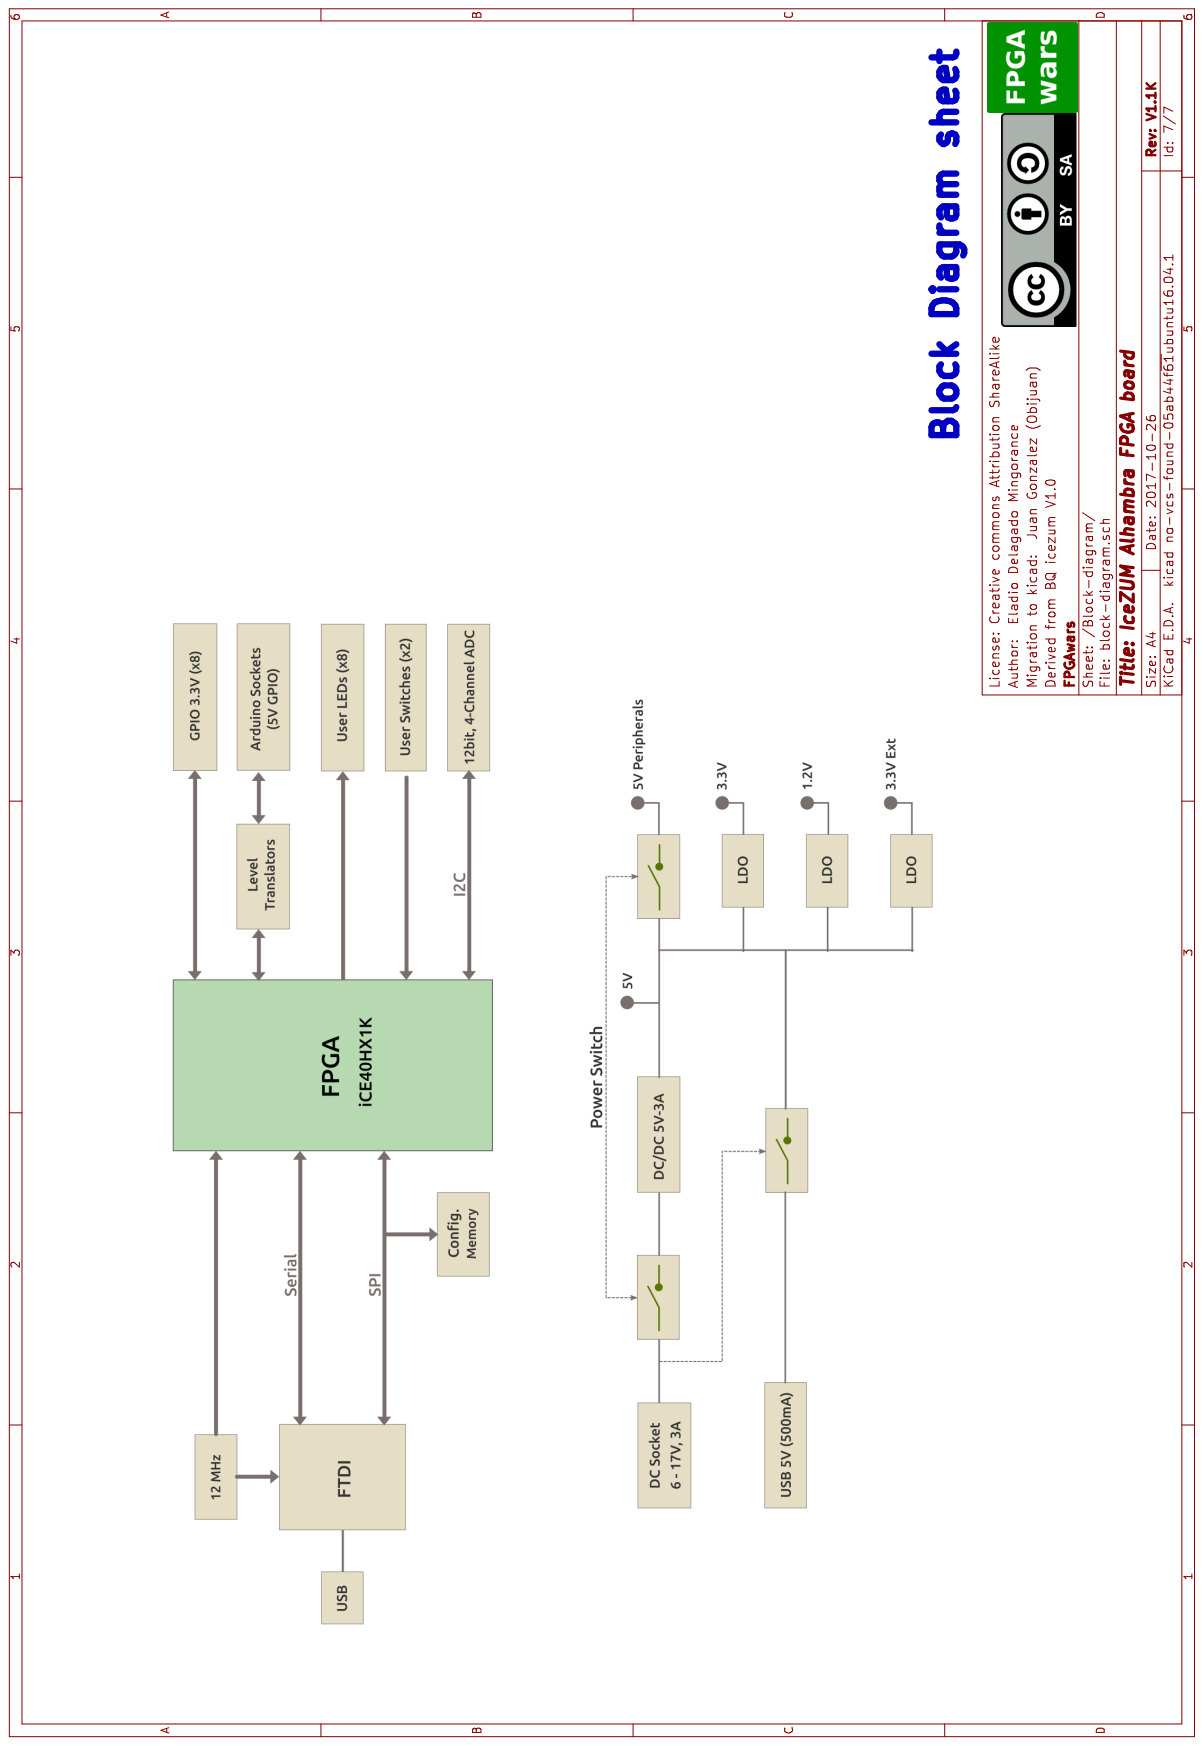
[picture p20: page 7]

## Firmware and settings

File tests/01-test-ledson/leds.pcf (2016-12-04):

# -----------------------------------------------------------------------------
#- Leds example for the Icezum board
#- Constraint file (.pcf)
# -----------------------------------------------------------------------------
# --  Repo: https://github.com/FPGAwars/icezum/wiki
# --  Pinout: https://github.com/FPGAwars/icezum/blob/master/doc/pinout/icezum-pinout.pdf

# ------------ User Leds ------------------------------------------------------
set_io  LED0  95
set_io  LED1  96
set_io  LED2  97
set_io  LED3  98
set_io  LED4  99
set_io  LED5  101
set_io  LED6  102
set_io  LED7  104

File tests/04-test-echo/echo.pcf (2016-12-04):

set_io leds[3] 96
set_io leds[2] 97
set_io leds[1] 98
set_io leds[0] 99
set_io rx   9
set_io tx   8
set_io clk  21

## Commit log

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2016-05-23 Fixed a bug in the pinout: adc sda, sdl pins corrected
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2016-05-24 Kicad migration: fpga sheet finished (not double checked yet)
    [fpga.sch, icezum.sch]
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2016-05-24 Kicad migration: TXB0108 Level translator added to the library
    [arduino-sockets.sch, fpga.sch]
2016-05-24 Kicad migration: some documentation on the arduino-sockets sheet
    [arduino-sockets.sch, icezum.sch]
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2016-05-25 Kicad migration: Power inputs control and protecctions added
    [Power-supply.sch]
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2016-05-28 Kicad migration: schematic initial version migrated. 0 errors in electrical rule check
    [arduino-sockets.sch, fpga.sch, usb-communications.sch]
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2016-05-28 Kicad schematic: fpga sheet: aligned to 50mils grid
    [fpga.sch, icezum.sch]
2016-05-28 Kicad schematic: added fpgawars logo and CC-BY-SA to all the sheets
    [Power-supply.sch, arduino-sockets.sch, fpga.sch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]
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2016-05-29 Kicad schematic: Sockets and headers sheet double checked
    [arduino-sockets.sch]
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2016-06-02 PCB migration to kicad: added led 3D model to local folder
    [icezum.kicad_pcb]
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2016-06-02 PCB kicad migration: LED_0603: added 3D model created from Freecad
    [icezum.kicad_pcb]
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2016-06-03 Kicad PCB migration: Leds D2 - D9 placed
    [icezum.kicad_pcb]
2016-06-03 Kicad PCB migration: R17 and R18 added, with 3D models
    [Power-supply.sch, arduino-sockets.sch, fpga.sch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]
2016-06-04 Kicad pcb migration: User switches added to the PCB
    [Power-supply.sch, arduino-sockets.sch, block-diagram.sch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]
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2016-06-06 Kicad PCB migration: Component U4 added (oscillator)
    [Power-supply.sch, arduino-sockets.sch, block-diagram.sch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]
2016-06-06 KICAD PCB migration: Capacitor C32 (smd c0402) added
    [Power-supply.sch, arduino-sockets.sch, block-diagram.sch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]
2016-06-06 Kicad pcb migration: Component U5 (serial eeprom memory) added
    [Power-supply.sch, arduino-sockets.sch, block-diagram.sch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]
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2016-06-06 Kicad pcb migration: Capacitors C21, C26 and C30
    [Power-supply.sch, arduino-sockets.sch, block-diagram.sch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]
2016-06-08 Kicad pcb migration: USB micro B smd connector added
    [Power-supply.sch, arduino-sockets.sch, block-diagram.sch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]
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2016-06-08 Kicad pcb migration. Ferrite bead L2 and L2 placed
    [Power-supply.sch, arduino-sockets.sch, block-diagram.sch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]
2016-06-09 Kicad pcb migration. R11 added. Some bug fixed in the schematics (R16 was missing)
    [Power-supply.sch, arduino-sockets.sch, block-diagram.sch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]
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2016-06-11 Kicad pcb migration. Components C17, C18, L1 and R10 placed
    [Power-supply.sch, arduino-sockets.sch, block-diagram.sch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]
2016-06-11 Kicad pcb migration. Capacitors C44, C39, C43, C38, C42, C40, C35, C34, C36, C37 added
    [icezum.kicad_pcb]
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2016-06-12 Kicad pcb migration: Component u3 (ftdi chip) added
    [Power-supply.sch, arduino-sockets.sch, block-diagram.sch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]
2016-06-12 Kicad pcb migration: Components c32, c6, c27, c20, r16 and tp3 added
    [Power-supply.sch, arduino-sockets.sch, block-diagram.sch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]
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2016-06-14 Kicad pcb migration: more resistors and capacitor added
    [icezum.kicad_pcb]
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2016-06-22 Kicad PCB migration: sw4 (reset) added
    [Power-supply.sch, icezum.kicad_pcb]
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2016-06-24 Kicad pcb migration: All the errors when importing the netlist have been removed
    [Power-supply.sch, arduino-sockets.sch, block-diagram.sch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]
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2016-06-26 Kicad pcb migration: Fiducial FD2 with correct values. Double checked
    [icezum.kicad_pcb]
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2016-07-08 Kicad pcb migration: fixed a bug in FTDI chip (pin 20 was duplicated) 220 nc links. 61 vias left
    [icezum.kicad_pcb]
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2016-07-08 Kicad pcb migration: Component U6: thermal pad added in schematics. 200 nc links. 24 vias left
    [Power-supply.sch, arduino-sockets.sch, block-diagram.sch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]
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2016-07-11 sw1 and sw2 silk was missing
    [icezum.kicad_pcb]
2016-07-11 Top layer zones: clearance set to 0.2mm (previously it was 0.09mm) which was wrong
    [icezum.kicad_pcb]
2016-07-11 3D model of Connector J18 was not correctly located (Reported by Eladio)
    [icezum.kicad_pcb]
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2016-07-12 Bug fixed in Edge.cuts: right tab was 50mils shorter than it should
    [icezum.kicad_pcb]
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2016-07-12 thermal relief via footprint added (for testing). Some tracks moved, to be at the same location than in the original gerber
    [icezum.kicad_pcb]
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2016-07-13 Kicad pcb: Some gnd vias with thermal relief. Removed some non-necesary gnd tracks
    [Power-supply.sch, arduino-sockets.sch, block-diagram.sch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]
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2016-07-13 Edge gerber file added, generated from kicad. Checked against the V1.0 gerber
    [icezum.GM1]
2016-07-13 Edge Clearance set to 0.4 (it was necessary to increase the edge line thickness to 0.68mm). Edge gerber re-generated
    [icezum.kicad_pcb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]
2016-07-13 Drills clearance increased to 0.6mm (in liberary footprint). Only changed in Drill2 in the PCB by now
    [icezum.kicad_pcb]
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2016-07-19 Some gndref vias has to be connected to gnd through a track. In kicad, vias without tracks are not allowed
    [icezum.kicad_pcb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]
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2016-07-19 Bug fixed: R17 and R18 resistor array: Changed the reference point (in silk screen) for the pad 1
    [icezum.kicad_pcb]
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2016-07-19 Silkscreen for the J2, J3, J6, J7, J8 and J9 components updated
    [icezum.kicad_pcb]
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2016-07-24 More 3D modelsrescaled and step files added (F_1812, MSOP-8, Xtal, LED, R_array, Xtal)
    [icezum.kicad_pcb]
2016-07-24 More 3D modes rescaled and .step files added (DO-214AC, SOD-323, SOT-23, SOT-563)
    [icezum.kicad_pcb]
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2016-07-24 R_0402 3D model rescaled. The 3D PCB can now be exported to Freecad using the Kicad Setup 3D tool script (from Freecad)
    [icezum.kicad_pcb]
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2016-07-24 Bug fixed: C31 capacitor is 4.7 uF, instead 4.7nF. Reported by JIM G. (github user @gh-jmg)
    [Power-supply.sch, arduino-sockets.sch, block-diagram.sch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]
2016-07-24 Icezum alhambra 3D model exported to Freecad and Step. The KicadSetup 3D Tool was used from Freecad
    [icezum.FCStd]
2016-07-26 R17 and R18 values fixed
    [Power-supply.sch, arduino-sockets.sch, block-diagram.sch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]
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2016-07-27 Removed the altium source files. All the information about V1.0K has been generated using only Opensource tools
    [IceZUM_Core_HX1K.PrjPcb, IceZUM_Core_HX1K.SchDoc, [1]_FPGA.SchDoc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]
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2016-07-27 DO-214AC: footprint images. Bug in the step file fixed
    [icezum.FCStd]
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2016-07-27 Small typo corrected in the BOM
    [icezum-bom.ods]
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2016-07-28 Added a keepout area near the C38-C44 capacitors for making it easier to solder the capacitors (Suggested by Eladio Delagado)
    [icezum.kicad_pcb]
2016-07-28 Increased the clearance between the via near the pad 20 on U9. Removed DRC errors
    [icezum.kicad_pcb]
2016-07-28 Clearance of The 2 vias near the C32 capacitor increased. They were too near to the pad
    [icezum.kicad_pcb]
2016-07-28 Increased the clearence of the Vias near C52 and C51. Too near to the pad
    [icezum.kicad_pcb]
2016-07-28 Increased the clearance of the via near C53. It was too near to the pad
    [icezum.kicad_pcb]
2016-07-28 Via near C53 moved away from the 5 on the silkscreen. It cannot be read well
    [icezum.kicad_pcb]
2016-07-28 Increased the clearance of via near R9. Too near to the pad
    [icezum.kicad_pcb]
2016-07-28 Increased the clearance on the two vias near the C45. Some re-routing has been done
    [icezum.kicad_pcb]
2016-07-28 More clearance to the vias near C59 and C3. They were too near to the pads
    [icezum.kicad_pcb]
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2016-08-26 sw_smd_6.0x3.8.wrl exported from kicadstepup. It should fixed issue #27
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2016-11-13 User test program: fixed a bug in the echo circuit, reported by Eladio Delgado
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2017-10-31 se añaden 4 capas nuevas para las capas de cobre de altium
    [icezum.kicad_pcb]
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2017-10-31 se eliminan las vias sobre los thermal pads y se sustituyen las huellas que incluyen las vias
    [icezum.kicad_pcb]
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2017-10-31 ajustes de pads en huellas tras comparar con gerbers exportados de altium
    [icezum.kicad_pcb]
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2017-10-31 se eliminan segmentos con ancho 0 fruto de la importacion de gerbers
    [icezum.kicad_pcb]
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2017-10-31 modificado error en asignacion de pines en pulsador 4p
2017-10-31 se completan vias y corrigen error posicionamiento. 10 UC nets
    [icezum.kicad_pcb]
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2017-11-01 Colocadas todas las vias y corregir error en simbolo de pulsadores 4p
    [Power-supply.sch, arduino-sockets.sch, block-diagram.sch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]
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2017-11-04 se cambia el nombre de la huella para los pulsadores y se actualiza en esquema y netlist
    [peripherals.sch]
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
